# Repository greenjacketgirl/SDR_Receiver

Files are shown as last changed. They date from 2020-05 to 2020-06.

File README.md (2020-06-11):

# SDR Receiver Project

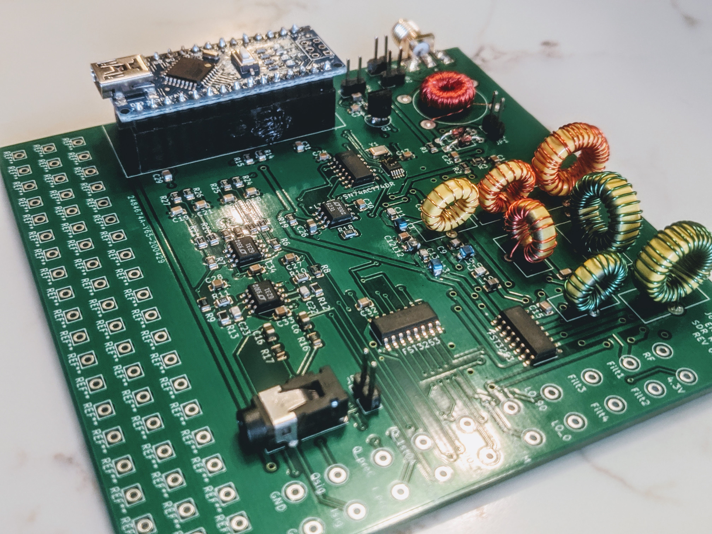
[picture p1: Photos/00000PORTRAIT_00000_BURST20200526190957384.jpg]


**Introduction** | This project was created in the scope of the the class ENGR 357 "Engineering Electronics II" conducted through online learning at Walla Walla University. We ([Jordyn Watkins](https://github.com/greenjacketgirl) and [Joshua Silver](https://github.com/JoshSilver8)) were tasked with designing, building, and testing a *software defined radio (SDR) receiver*. Our radio is designed to listen to frequencies ranging from 500kHz - 50MHz designed to be used in conjunction with [Quisk](https://github.com/greenjacketgirl/SDR_Receiver/wiki/9.-Software), a free open source SDR software. For more information on the theory, reasoning behind our design choices, and a more in depth look at the results and specs of this project, please refer to the [Wiki](https://github.com/greenjacketgirl/SDR_Receiver/wiki) tab.

**Navigation** | This repository consists of several folders. In this "code" tab, you will find 2 primary folders: Attenuator and Receiver. Within the attenuator file, you will find a folder containing the KiCad files, a folder containing the LTspice simulation files, and a third folder containing build and test notes with pictures and other documentation. The Receiver folder contains 4 main folders: KiCad, LTSpice, Quisk, and Documentation.

**Results** | The radio is in working condition - producing low noise I and Q signals 90 degrees out of phase. The signal discernability is very good, being able to detect signals as small as 0.5uV, and the image rejection is also decent having a 30dB difference between signal and image. For more details on the specs for the radio, visit the [Results](https://github.com/greenjacketgirl/SDR_Receiver/wiki/Results) in the [Wiki](https://github.com/greenjacketgirl/SDR_Receiver/wiki).

**Credits** | This project was created with a lot of help from our professor, Dr. Frohne. The files under the Quisk folder are primarily his. See his github profile at https://github.com/frohro/ 

**Status of Project** | Visit the "issues" tab to see errors and fixes for this project - which should provide a more in depth explanation for the quote "status" of the project. You can also visit the "Wiki" page or view the documentation files in the folders for a description of build and test process when troubleshooting issues.

REVISION 1: _05/26/2020  Build Phase and Troubleshooting Hardware_ |
REVISION 2: _06/04/2020 Test Phase and Troubleshooting Quisk Software Integration_ | REVISION 3: _06/10/2020 Working Radio Fine Tuning and Adjustments_

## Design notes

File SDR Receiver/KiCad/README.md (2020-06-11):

# Navigating this folder

This folder contains two versions of the schematic and pcb design. The first design is the collection of files shown. The second revision is located in the folder [Kicad-V2](https://github.com/greenjacketgirl/SDR_Receiver/tree/master/SDR%20Receiver/KiCad/Kicad-V2). This second revision is the schematic updated with the corrections made by hand shown in the [Issues tab](https://github.com/greenjacketgirl/SDR_Receiver/issues). Note that this second revision only has an updated schematic, not an updated pcb. Thus, future work will require further revision of the PCB. 

Primary corrections made in this second revision:
* crystal footprint pin numbers corrected
* pull up resistors on si5351 clock generator connected to VCC instead of GND
* bandpass filter wiring correction on multiplexer
* label correction from tayloe mixer to summing op-amps

I tried to include the .pretty and library files for the footprints and schematic symbols I used. If you have a difficult time seeing the footprints for some reason, you can also refer to our digikey BOM in the [documents section](https://github.com/greenjacketgirl/SDR_Receiver/tree/master/SDR%20Receiver/Documentation) to look up the part on the [digikey website](https://www.digikey.com) and download the respective footprint from there. You may need to also make corrections to the PCB board after uploading a new symbol and footprint .pretty file.

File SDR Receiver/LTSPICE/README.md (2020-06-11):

**LTspice Simulations |** A description of what each simulation file models

* The [BypassFilterSim](https://github.com/greenjacketgirl/SDR_Receiver/blob/master/SDR%20Receiver/LTSPICE/BypassFilterSim.asc) file essentially contains the simulation of the entire board: Input signal biasing, bandpass filters, tayloe mixer, summing amps, and low-pass filter. This simulation inludes a transients analysis as well as an ac analysis which was useful for the analysing the bandpass filters. We started to attempt a simulation of the noise in the circuit - but this analysis isn't complete yet and is something that can be addressed as future work in the project. See the [issues section number 10 thread](https://github.com/greenjacketgirl/SDR_Receiver/issues/10) for more info on this goal. 

* The [TayloeMixerSim](https://github.com/greenjacketgirl/SDR_Receiver/blob/master/SDR%20Receiver/LTSPICE/TayloeMixerSim.asc) is just a simulation nof the tayloe mixer and following op-amps. In there, I was experimenting with different filter and amplification designs. The final design I went with was included in the [BypassFilterSim](https://github.com/greenjacketgirl/SDR_Receiver/blob/master/SDR%20Receiver/LTSPICE/BypassFilterSim.asc) file.

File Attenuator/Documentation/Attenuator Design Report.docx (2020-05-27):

Attenuator Design

Criteria: We need a step attenuator capable of going from 5mV, zero to peak, to 1uV RMS or maybe 0.5uV RMS, to test our radio receivers using the Analog Discovery 2 boards from Digilent. You should download and install the Waveforms program. You can run it before you receive your Analog Discovery 2 board and see that the lowest output from the board is 5mV, zero to peak. It is important that you realize the stray capacitance and mutual inductance can bypass your attenuator if you don’t design it correctly. We need these attenuators to work to at least 30MHz. I suggest using at least five stages, and 0.1” headers and jumpers for the switches needed. Model your design in LTSpice for the highest attenuation at 30 MHz to make sure it will work. If you have trouble, contact me, and I can help. I have only done a very quick approximation to be fairly certain this should be possible. Then design the PCB in KiCad. As you do, try to make the traces have a characteristic impedance, Z0 of fifty ohms. There is a calculator in KiCad that will help you with that problem. You can choose if you want surface mount or through hole components. We are sending you soldering irons, but they probably are not as good as the school’s irons, so soldering surface mount components may be more difficult for you.

Design: I started by determining the amount of attenuation we needed in terms of decibels. This was done using the equation:

dB_v =20log_10 ((V_(OUT))/(V_(IN)))dB

where in our case, V_(OUT) =0.5μV and V_(IN) =5mV . Thus, our decibel attenuation was determined to be:

dB_v =20log_10 ((0.5×10^(-6))/(5×10^(-3)))dB=-80 dB

We can now design our attenuator so that we have a total decibel drop close to 80. However, to compensate for the capacitance in the circuit (capacitance values calculate in appendix A), and to adjust to have a value of around 0.5μV at a frequency of 20MHz while having minimal distortion at 30MHz , we chose a loss of 74 dB. The stray capacitance was factored into the simulation, but mutual inductance was neglected, as we presumed that it would be negligible since we planned on constructing the attenuator in a linear fashion. We decided to have 5 stages, each with a loss of 14.8 dB for simplicity and to minimize the amount of distortion the circuit sees at higher frequencies. To calculate the resistor values, we performed the following calculations, whose results are summarized in table 1.

K=10^(15/20) =5.49541

R1,R3=Z((K+1)/(K-1))=50((5.49541+1)/(5.49541-1))=71.629Ω

R2=Z((K^2 +1)/(2K))=Z((5.49541^2 +1)/(2(5.49541)))=136.14 Ω

We then looked a common resistor value table and took the closest actual resistor values to place in our simulation in LTSpice.

dB Loss | K Factor | 50 Ω Impedence
| | R1, R3 | R2
14.8 | 5.49541 | 73.2 | 133

Table 1. Calculated resistor values based on a 15 dB attenuation per stage of the attenuator circuit.

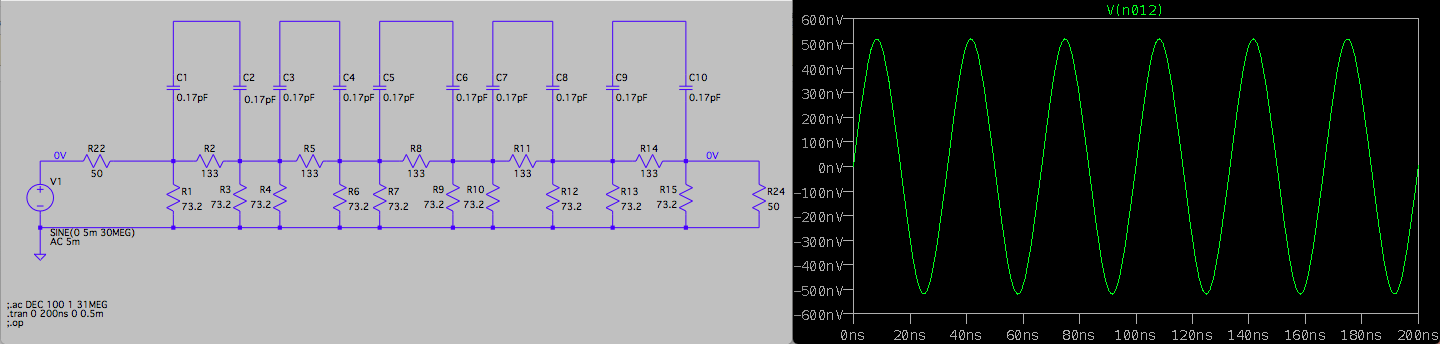
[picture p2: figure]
../../../../Dropbox/Screenshots/Screenshot%202020-04-02%2013.54.24.p
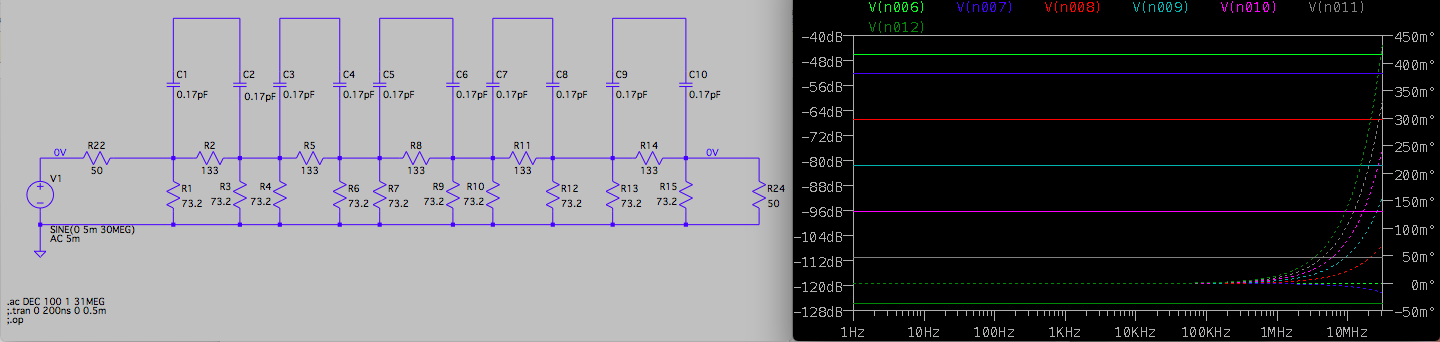
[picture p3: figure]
../../../../Dropbox/Screenshots/Screenshot%202020-04-02%2013.55.32.p

Simulation: The LTSpice simulation was modeled as shown in Figure 1 and Figure 2. From these simulations, we see that even with the stray capacitance factored into the simulation, the circuit functions as expected. An input signal of 5mV is attenuated to somewhere between 0.35uV to 1uV depending on the frequency of the signal.

Figure 2. The attenuator circuit simulation in LTSpice with transient analysis shown on the right at a frequency of 20MHz and input signal of amplitude 5mV. We see that the output voltage is just at 0.5uV therefore meeting the design criteria.

Figure 1.The attenuator circuit simulation in LTSpice with ac analysis shown on the right, with probes at each stage in the attenuator. The magnitude across the load resistor starts at -128dB, increasing to -126.8dB by 32MHz.

PCB Design: We used KiCad to design our PCB. We are using jumpers between pins as our pseudo switches, therefore 1x3 connectors were used to model each switch. We decided on using through hole resistors (THT-resistors) for ease of soldering them onto the completed board. For power supply to the board, we used coaxial connectors. The parts list is provided in the figure below, along with documentation of the KiCad Schematic and PCB Design. We ordered the boards to be printed from JLC PCB.

Resistor_THT:R_Axial_DIN0207_L6.3mm_D2.5mm_P7.62mm_Horizontal

PCB calculator:

TRANSLINE

Microstrip Line

Ordered from JLC PCB

Appendix A: Created by Dr. Frohne

Jordyn Watkins ENGR 357 Attenuator Design 04/03/2020

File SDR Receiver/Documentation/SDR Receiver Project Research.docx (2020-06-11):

SDR Receiver Project Research

Quadrature Mixers, IQ Demodulation, and the Tayloe Detector

Reference: https://www.youtube.com/watch?v=JuuKF1RFvBM

MIXER DESIGN: When we talk about mixers, we are usually implying we are talking about multiplying mixers.

sin(w_1 t)sin(w_2 t)=1/2cos(w_1 w_2 )t-1/2cos(w_1 w_2 )t

+/- IF

RF

LO

Essentially, the local oscillator acts as a theoretical “switch” that turns on and off. In order to tell if we are at the +IF or the –IF, we need a reference frequency. And that’s when we need a phase parameter as our reference. Thus, we need waves 90 degrees out of phase with each other out of the output (the I and Q signals). We essentially need to take our input signal (RF) and break it down into two smaller components (I and Q).

If we have a signal positive with respect to the local oscillator, then we have this equation:

e^(jwt) =cos(wt)+jsin(wt) where cos(wt) is the I signal, and jsin(wt) is the Q signal.

The I wave is leading and the Q wave is lagging.

If we have a signal negative with respect to the local oscillator, then we have this equation:

e^(-jwt) =cos(wt)-jsin(wt) where cos(wt) is the I signal, and jsin(wt) is the Q signal.

The Q wave is leading, and the I wave is lagging.

So, when we talk about I and Q, we mean that the I signal is the “in phase” or our “reference” signal which is static (as indicated by the equation where the cosine term is unchanged in the equations. And the Q signal is the quadrature signal. It is essentially flipped 180 degrees so that it appears like it is either leading or lagging the I signal by 90 degrees. If it is lagging, then it is above our local oscillator frequency, whereas if it is leading, then it is below the local oscillator frequency.

Using a Tayloe Mixer: utilizes 4 to 1 multiplexer IC. Called Dan tayloe mixers after the guy who popularized them. Only need one multiplexer, they are very cheap (about 50 cents apiece), they require very low local oscillator drive levels (don’t need a lot of power out of your local oscillator), have high 3rd order intercept (so immune to being overloaded by strong levels), and have very low insertion loss (about 1dB). How they work: they have select lines s0 and s1, where the I signal of the local oscillator connects to s0 and the Q signal of the local oscillator connects to s1. Since the I and Q signals are 90 degrees out of phase, we essentially see this as an input to the tayloe mixer select lines:

00 01 11 10 00 01 11 10 00 01 11 10

So the input signal into the multiplexer will be the RF signal, and the output will be a combination of 0, 90, 180, and 270 degree signals. Each one *starts sampling at the corresponding degree. Thus, we have each of the four signals out of phase with the next.

Note, we need capacitors on the outputs of the tayloe mixer multiplexer. The purpose of these capacitors is to sample and hold the voltage that they see. They will track whatever voltage they see while the RF signal is connected to them.

For instance – when the RF and LO signals are the same, we will see that the 0 deg will be the peak voltage value, the 90 deg will be at 0V, and the 180 deg at the minimum voltage value, and the 270 deg will again be at 0V. BUT, if the RF and LO are at slightly different frequencies, then instead of seeing the maximum, minimum and 0V, we will instead start to see this phase shift at the frequency difference over time. Thus, we have our down-converted signal, but in four parts instead of just two. These are our quadrature outputs. Where 0 deg is complimentary to 180 deg, and 90 deg is complimentary to 270 deg. So, these complimentary outputs are put into a summing amp so that we aren’t throwing away any signals. Classically, we use the FST3253, which is a dual 4 to 1 multiplexer. Typically, the RF signal is actually applied to both of the inputs on the dual multiplixer – and this is just done to lower the resistance that the chip provides to the signal. The typical resistance is 4 ohms, but if you use two inputs, then it lowers it to 2 ohms. The corresponding outputs are also tied together for the same reason.

The way you select the sample capacitors is to set the low pass cut off frequency that you want. This essentially becomes a low pass filter when examined in conjunction with the 50 ohm impedence of the input signal. But it’s important to note that the input resistance is split between 4 outputs, so each output only sees ¼ of the input resistance, which is 50/4 = 12.5 ohms. But then we also need to add in the resistance from the multiplexer.

jX = 1/(jwC) => 12.5 = 1/(2*pi*f*C). If we choose a cut off frequency, then we can calculate the capacitance for this low pass filter.

BANDPASS FILTER DESIGN:

CRYSTAL AND CLOCK GENERATOR FOR LOCAL OSCILLATOR:

SUMMING AMPS AND LOW PASS FILTER DESIGN:

Jordyn Watkins ENGR 357 04/06/2020

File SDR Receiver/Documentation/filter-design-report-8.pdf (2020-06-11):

## Filter Design Report

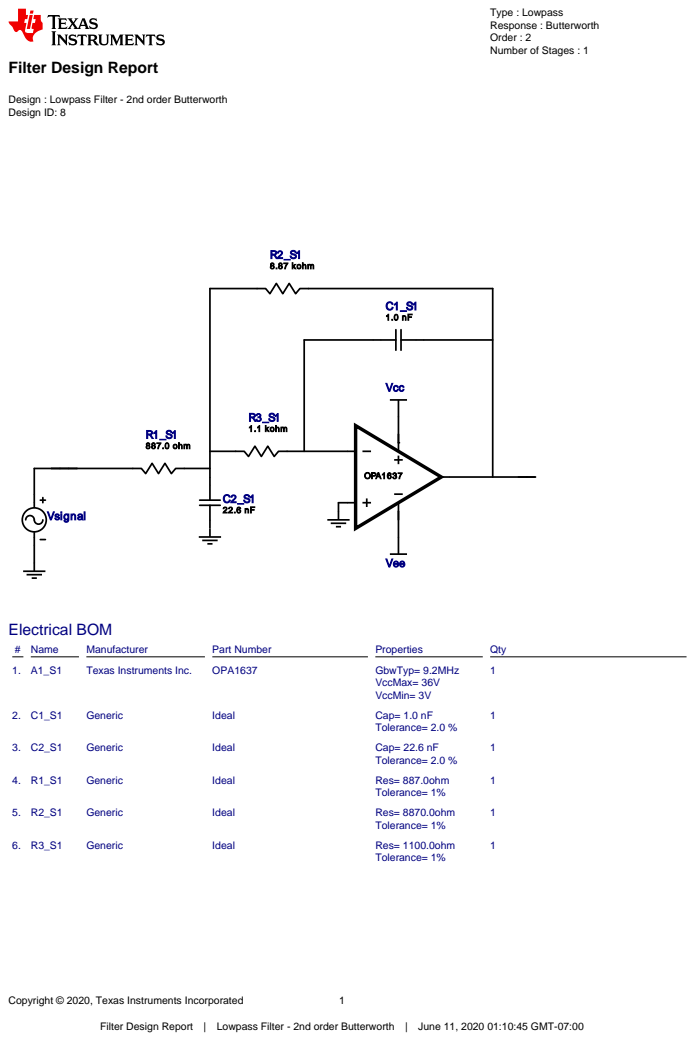
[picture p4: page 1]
Copyright © 2020, Texas Instruments Incorporated; Vsignal; OPA1637; R1_S1 887.0 ohm; R2_S1 8.87 kohm; R3_S1 1.1 kohm; Vcc; Vee; Electrical BOM; # Name; Manufacturer; Part Number; Properties; Qty; Texas Instruments Inc.; GbwTyp= 9.2MHz; VccMax= 36V VccMin= 3V; Generic; Ideal; Cap= 1.0 nF; Tolerance= 2.0 %; Cap= 22.6 nF; Res= 887.0ohm; Tolerance= 1%; Res= 8870.0ohm; Res= 1100.0ohm

Type : Lowpass
Response : Butterworth
Order : 2
Number of Stages : 1

Design : Lowpass Filter - 2nd order Butterworth
Design ID: 8

Filter Design Report | Lowpass Filter - 2nd order Butterworth | June 11, 2020 01:10:45 GMT-07:00

Filter Design

## Sensitivity Analysis

# Name | Series | Tolerance

1. Cap | E48 | 2%
2. Res | E96 | 1%

## Design Inputs

# | Name | Value | Description

1. FilterType | lowpass
2. FilterResponse | Butterworth
3. FilterOrder | 2.0
4. FilterTopology | Multiple Feedback
5. NumberOfStages | 1.0
6. PassbandFrequency | 10.7 k
7. StopbandAttenuation | -40.001
8. StopbandFrequency | 107.0 k
9. Gain | 10.0
10. DualSupply | +/-5.00 V | Power supply(s) to active chips
11. ResistorTolerance | E96 | Resistor series - 1% Passive resistor tolerance
12. CapacitorTolerance | E48 | Capacitor series - 2% Passive capacitor tolerance

## Design Assistance

1. OPA1637 Product Folder : http://www.ti.com/product/OPA1637 : contains the data sheet and other resources.

# Filter Stage :1

Cutoff Frequency | 10.718 kHz
Min GBW Reqd | 7.566 MHz
Stage Gain | 10.0 V/V
Stage Q | 708.132 m
Stage Topology | Multiple Feedback
| R2_S1 8.87 kohm

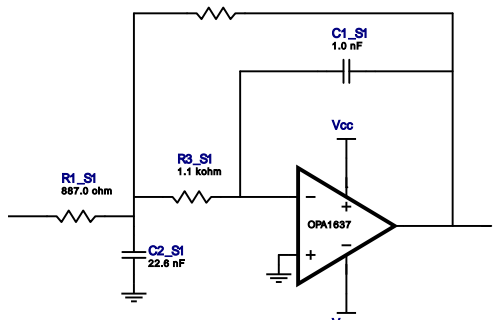
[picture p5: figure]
OPA1637; R1_S1 887.0 ohm; R3_S1 1.1 kohm; Vcc

Vee

## Electrical BOM

# Name | Manufacturer | Part Number | Properties | Qty

1. A1_S1 | Texas Instruments Inc. | OPA1637 | GbwTyp= 9.2MHz VccMax= 36V VccMin= 3V | 1
2. C1_S1 | Generic | Ideal | Cap= 1.0 nF Tolerance= 2.0 %

1

3. C2_S1 | Generic | Ideal | Cap= 22.6 nF Tolerance= 2.0 %

1

4. R1_S1 | Generic | Ideal | Res= 887.0ohm Tolerance= 1%

1

5. R2_S1 | Generic | Ideal | Res= 8870.0ohm Tolerance= 1%

1

6. R3_S1 | Generic | Ideal | Res= 1100.0ohm Tolerance= 1%

1

Important Notice and Disclaimer

TI provides technical and reliability data (including datasheets), design resources (including reference designs), application or other design advice, web tools, safety information, and other resources AS IS and with all faults, and disclaims all warranties. These resources are intended for skilled developers designing with TI products. You are solely responsible for (1) selecting the appropriate TI products for your application, (2) designing, validating and testing your application, and (3) ensuring your application meets applicable standards, and any other safety, security, or other requirements.

These resources are subject to change without notice. TI grants you permission to use these resources only for development of an application that uses the TI products described in the resource. Other reproduction and display of these resources is prohibited. No license is granted to any other TI intellectual property right or to any third party intellectual property right. TI disclaims responsibility for, and you will fully indemnify TI and its representatives against, any claims, damages, costs, losses, and liabilities arising out of your use of these resources.

Providing these resources does not expand or otherwise alter TI's applicable Terms of Sale or other applicable terms available either on ti.com or provided in conjunction with TI products.

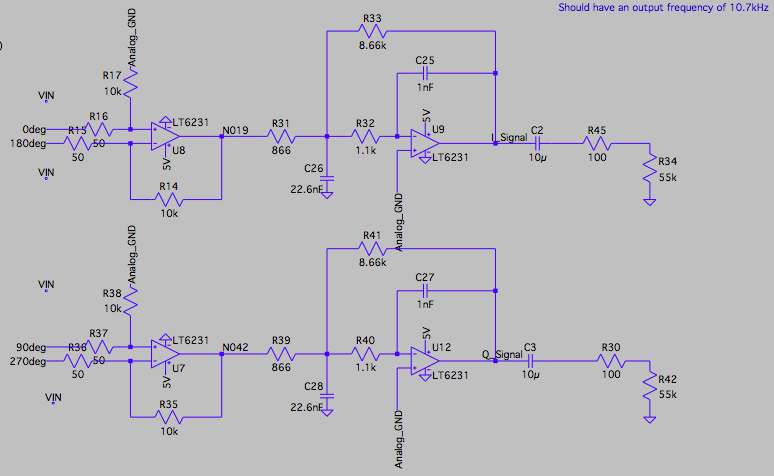
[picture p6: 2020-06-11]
Photos/Screenshot 2020-06-11 01.46.17.png

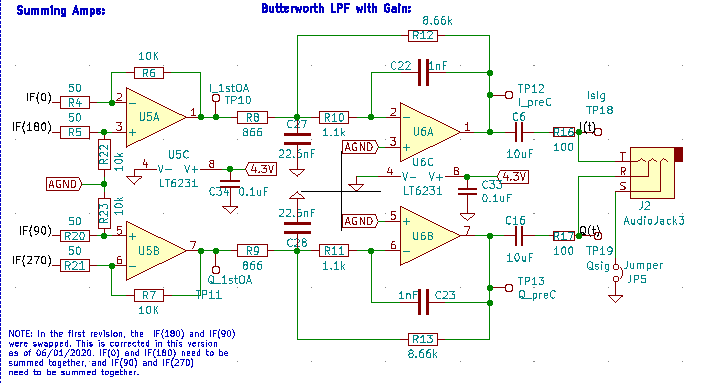
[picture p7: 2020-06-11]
Photos/Screenshot 2020-06-05 09.06.02.png

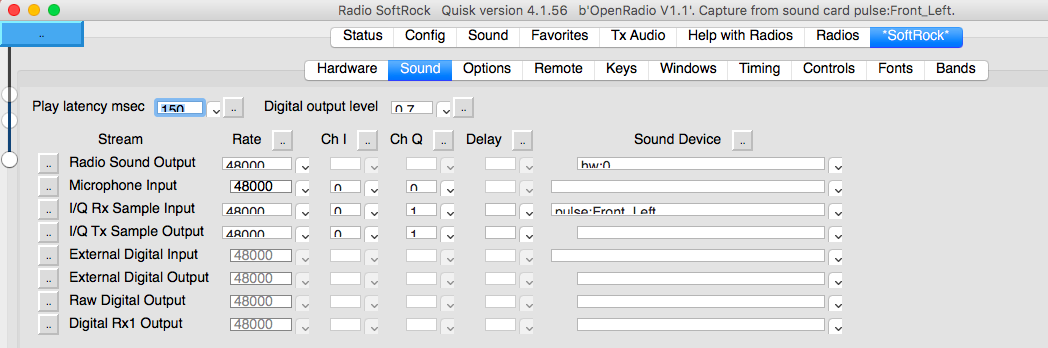
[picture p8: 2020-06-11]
Photos/Screenshot 2020-06-01 17.20.05.png

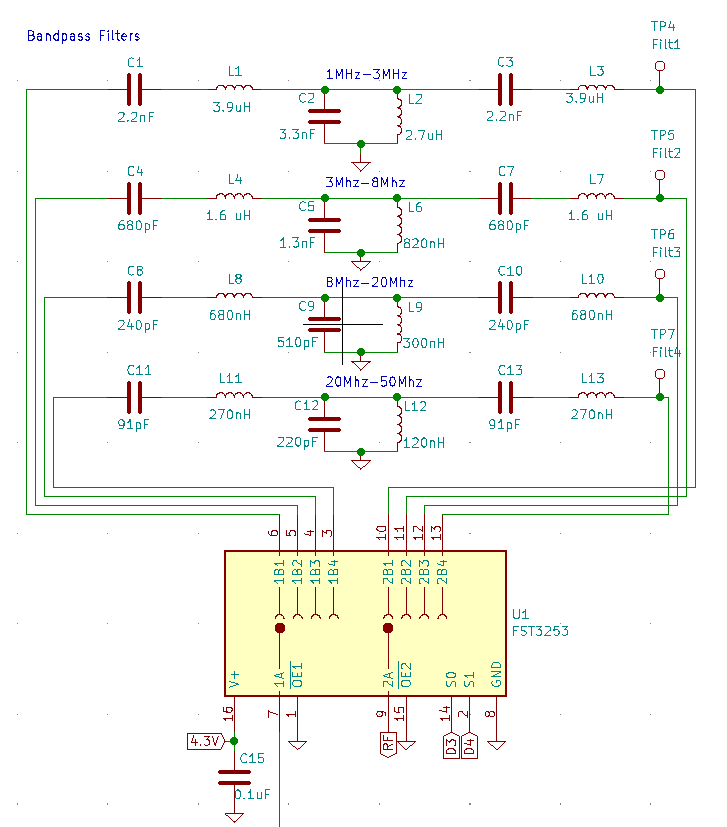
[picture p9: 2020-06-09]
Photos/Bandpass Filter Sch.png

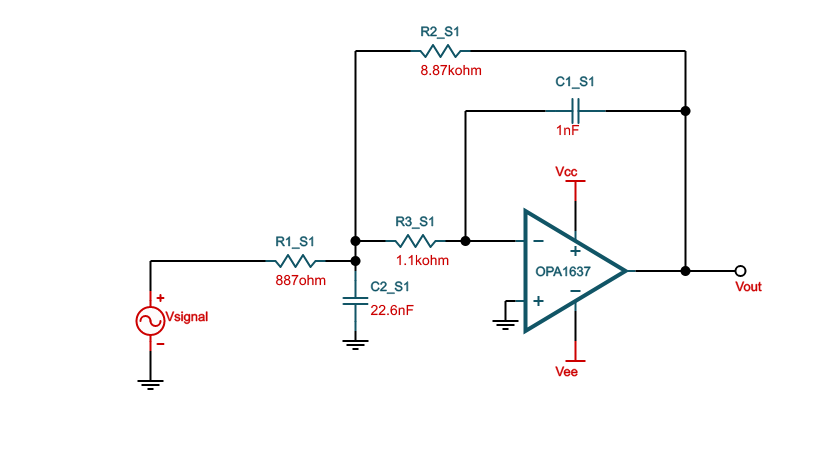
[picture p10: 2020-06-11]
Photos/Screenshot 2020-06-11 01.09.24.png

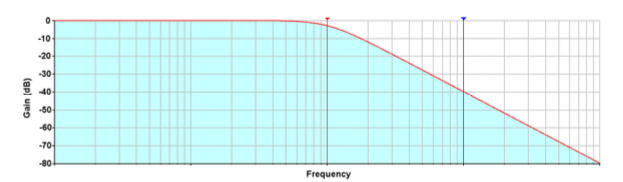
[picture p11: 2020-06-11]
Photos/Screenshot 2020-06-11 00.57.46.png

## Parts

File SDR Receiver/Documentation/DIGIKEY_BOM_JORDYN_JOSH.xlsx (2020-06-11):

Manufacturer Part Number | Manufacturer | Digi-Key Part Number | Customer Reference | Reference Designator | Packaging | Part Status | Quantity | Unit Price | Extended Price | Quantity Available | Mfg Std Lead Time | Description | RoHS Status | Lead Free Status | REACH Status
C0805C104Z5VACTU | KEMET | 399-1177-1-ND |  |  | Cut Tape (CT) | Active | 12 | 0.057 | $0.68 | 743266 | 8 Weeks | CAP CER 0.1UF 50V Y5V 0805 | ROHS3 Compliant | Lead free | REACH Unaffected
C0805C106K8PACTU | KEMET | 399-4925-1-ND |  |  | Cut Tape (CT) | Active | 4 | 0.16 | $0.64 | 311400 | 13 Weeks | CAP CER 10UF 10V X5R 0805 | ROHS3 Compliant | Lead free | REACH Unaffected
C0805C222KARACAUTO | KEMET | 399-16649-1-ND |  |  | Cut Tape (CT) | Active | 2 | 0.29 | $0.58 | 14279 | 11 Weeks | CAP CER 0805 2.2NF 250V X7R 10% | ROHS3 Compliant | Lead free | REACH Unaffected
C0805C332KDRACAUTO | KEMET | 399-16654-1-ND |  |  | Cut Tape (CT) | Active | 1 | 0.46 | $0.46 | 3842 | 11 Weeks | CAP CER 0805 3.3NF 1000V X7R 10% | ROHS3 Compliant | Lead free | REACH Unaffected
CC0805KRX7R9BB681 | Yageo | 311-1126-1-ND |  |  | Cut Tape (CT) | Active | 2 | 0.12 | $0.24 | 73294 | 33 Weeks | CAP CER 680PF 50V X7R 0805 | ROHS3 Compliant | Lead free | REACH Unaffected
GRM2165C2A132JA01D | Murata Electronics | 490-8290-1-ND |  |  | Cut Tape (CT) | Active | 1 | 0.19 | $0.19 | 5041 | 10 Weeks | CAP CER 1300PF 100V C0G/NP0 0805 | ROHS3 Compliant | Lead free | Not Available
C0805C910J5GACTU | KEMET | 399-9279-1-ND |  |  | Cut Tape (CT) | Active | 2 | 0.33 | $0.66 | 5865 | 8 Weeks | CAP CER 91PF 50V C0G/NP0 0805 | ROHS3 Compliant | Lead free | REACH Unaffected
C0805C221M5RACTU | KEMET | 399-8039-1-ND |  |  | Cut Tape (CT) | Active | 1 | 0.1 | $0.10 | 94549 | 8 Weeks | CAP CER 220PF 50V X7R 0805 | ROHS3 Compliant | Lead free | REACH Unaffected
C0805C241J5GAC7800 | KEMET | 399-15478-1-ND |  |  | Cut Tape (CT) | Active | 2 | 0.33 | $0.66 | 5228 | 11 Weeks | CAP CER 240PF 50V NP0 0805 | ROHS3 Compliant | Lead free | REACH Unaffected
C0805C511J5HACAUTO | KEMET | 399-16590-1-ND |  |  | Cut Tape (CT) | Active | 1 | 0.19 | $0.19 | 6248 | 11 Weeks | CAP CER 0805 510PF 50V ULTRA STA | ROHS3 Compliant | Lead free | REACH Unaffected
08051C163JAT2A | AVX Corporation | 478-10426-1-ND |  |  | Cut Tape (CT) | Active | 4 | 0.37 | $1.48 | 22784 | 12 Weeks | CAP CER 0.016UF 100V X7R 0805 | ROHS3 Compliant | Lead free | REACH Unaffected
C0805C102J5HACAUTO | KEMET | 399-16591-1-ND |  |  | Cut Tape (CT) | Active | 2 | 0.19 | $0.38 | 12845 | 11 Weeks | CAP CER 0805 1NF 50V ULTRA STABL | ROHS3 Compliant | Lead free | REACH Unaffected
C0805C223K5RACTU | KEMET | 399-1163-1-ND |  |  | Cut Tape (CT) | Active | 2 | 0.1 | $0.20 | 402335 | 8 Weeks | CAP CER 0.022UF 50V X7R 0805 | ROHS3 Compliant | Lead free | REACH Unaffected
LT6231CS8#PBF | Linear Technology/Analog Devices | LT6231CS8#PBF-ND |  |  | Tube | Active | 3 | 4.85 | $14.55 | 2241 | 10 Weeks | IC OPAMP GP 2 CIRCUIT 8SO | ROHS3 Compliant | Lead free | REACH Unaffected
SN74CBT3253CDR | Texas Instruments | 296-19206-1-ND |  |  | Cut Tape (CT) | Active | 2 | 0.58 | $1.16 | 5971 | 6 Weeks | IC MUX/DEMUX DUAL 4:1 16SOIC | ROHS3 Compliant | Lead free | REACH Unaffected
1N914 | ON Semiconductor | 1N914FS-ND |  |  | Bulk | Active | 2 | 0.1 | $0.20 | 14503 | 18 Weeks | DIODE GEN PURP 100V 200MA DO35 | ROHS3 Compliant | Lead free | REACH Unaffected
SN74ACT74DR | Texas Instruments | 296-1079-1-ND |  |  | Cut Tape (CT) | Active | 1 | 0.5 | $0.50 | 2491 | 6 Weeks | IC FF D-TYPE DUAL 1BIT 14SOIC | ROHS3 Compliant | Lead free | REACH Unaffected
FA-238 25.0000MB-C3 | EPSON | SER3691CT-ND |  |  | Cut Tape (CT) | Active | 1 | 0.36 | $0.36 | 17296 | 16 Weeks | CRYSTAL 25.0000MHZ 18PF SMD | ROHS3 Compliant | Lead free | Not Available
0805CS-271EKTS | Delta Electronics/Components | 2035-1233-1-ND |  |  | Cut Tape (CT) | Active | 2 | 0.25 | $0.50 | 3990 | 16 Weeks | CHIP INDUCTOR 270NH10% 350MA 1.0 | ROHS3 Compliant | Lead free | Not Available
CV201210-R68K | Bourns Inc. | CV201210-R68KCT-ND |  |  | Cut Tape (CT) | Active | 1 | 0.1 | $0.10 | 2375 | 18 Weeks | FIXED IND 680NH 150MA 800MOHM SM | ROHS3 Compliant | Lead free | REACH Unaffected
PE-0805CM121JTT | Pulse Electronics Network | 553-1043-1-ND |  |  | Cut Tape (CT) | Active | 1 | 0.31 | $0.31 | 12696 | 70 Weeks | FIXED IND 120NH 350MA 560 MOHM | RoHS Compliant | Lead free | Not Available
0805CS-301EGTS | Delta Electronics/Components | 2035-1241-1-ND |  |  | Cut Tape (CT) | Active | 1 | 0.25 | $0.25 | 3850 | 16 Weeks | CHIP INDUCTOR 300NH2% 330MA 1.2O | ROHS3 Compliant | Lead free | Not Available
RC0805FR-0710KL | Yageo | 311-10.0KCRCT-ND |  |  | Cut Tape (CT) | Active | 6 | 0.1 | $0.60 | 23482238 | 24 Weeks | RES SMD 10K OHM 1% 1/8W 0805 | ROHS3 Compliant | Lead free | REACH Unaffected
RC0805FR-074K7L | Yageo | 311-4.70KCRCT-ND |  |  | Cut Tape (CT) | Active | 2 | 0.1 | $0.20 | 2940632 | 24 Weeks | RES SMD 4.7K OHM 1% 1/8W 0805 | ROHS3 Compliant | Lead free | REACH Unaffected
RC0805FR-072K2L | Yageo | 311-2.20KCRCT-ND |  |  | Cut Tape (CT) | Active | 1 | 0.1 | $0.10 | 3594454 | 24 Weeks | RES SMD 2.2K OHM 1% 1/8W 0805 | ROHS3 Compliant | Lead free | REACH Unaffected
ERA-6AEB8661V | Panasonic Electronic Components | P8.66KDACT-ND |  |  | Cut Tape (CT) | Active | 2 | 0.34 | $0.68 | 4997 | 12 Weeks | RES 8.66K OHM 0.1% 1/8W 0805 | ROHS3 Compliant | Lead free | REACH Unaffected
ERJ-PB6B1101V | Panasonic Electronic Components | P20598CT-ND |  |  | Cut Tape (CT) | Active | 2 | 0.36 | $0.72 | 7877 | 12 Weeks | RES SMD 1.1K OHM 0.1% 1/4W 0805 | ROHS3 Compliant | Lead free | Not Available
CRCW0805866RFKEA | Vishay Dale | 541-866CCT-ND |  |  | Cut Tape (CT) | Active | 2 | 0.1 | $0.20 | 23542 | 11 Weeks | RES SMD 866 OHM 1% 1/8W 0805 | ROHS3 Compliant | Lead free | Not Available
ERJ-6ENF49R9V | Panasonic Electronic Components | P49.9CCT-ND |  |  | Cut Tape (CT) | Active | 4 | 0.1 | $0.40 | 350805 | 16 Weeks | RES SMD 49.9 OHM 1% 1/8W 0805 | ROHS3 Compliant | Lead free | REACH Unaffected
CRG0805F47R | TE Connectivity Passive Product | A126371CT-ND |  |  | Cut Tape (CT) | Active | 4 | 0.1 | $0.40 | 34663 | 16 Weeks | RES SMD 47 OHM 1% 1/8W 0805 | RoHS Compliant | Lead free | Not Available
RC0805JR-071KL | Yageo | 311-1.0KARCT-ND |  |  | Cut Tape (CT) | Active | 1 | 0.1 | $0.10 | 4848264 | 24 Weeks | RES SMD 1K OHM 5% 1/8W 0805 | ROHS3 Compliant | Lead free | REACH Unaffected
BC547BTA | ON Semiconductor | BC547BTACT-ND |  |  | Cut Tape (CT) | Active | 1 | 0.2 | $0.20 | 6111 | 12 Weeks | TRANS NPN 45V 0.1A TO-92 | ROHS3 Compliant | Lead free | REACH Unaffected
SI5351A-B-GT | Silicon Labs | 336-2399-5-ND |  |  | Tube | Active | 1 | 0.92 | $0.92 | 736 | 6 Weeks | IC CLK GENERATOR 200MHZ 10MSOP | Not Available | Lead free | Not Available

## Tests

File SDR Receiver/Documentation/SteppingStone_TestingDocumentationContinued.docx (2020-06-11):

Testing Continued

Since the attenuator is completely working, no further tests were needed for that board. Returning back to the testing of the SDR Receiver, I picked off of where I was last week. Last week, I still needed to rewire the bandpass filters (as this was thought to be the cause of frying the arduino nano). I was able to successfully cut the traces and find some wire I could use to re-solder the pins to the right places. After I finished doing this, I used a multimeter to test the connections to make sure that they were solid. Once I had done everything I could to make sure the bandpass filters were wired correctly, and I had explored any other possibility of the Arduino frying, I mustered up some courage and tried plugging in my Arduino nano once again. This time, it did not burn anything! So, the incorrect wiring in the bandpass filters was, in fact, the problem.

However, an issue remained. I had programmed the Arduino to select the 2nd bandpass filter, but it was still selecting the first filter. After checking the datasheet for the multiplexer, checking my code, and checking the board with no luck – I decided that I could afford to tackle this problem at another time. I figured this was something I could work on after I knew I had the rest of the board working since I knew I had at least the first bandpass filter working.

Proceeding to test the rest of the board, I put in a 760kHz as the input signal, and set the si5351 chip output to 3MHz, so that the local oscillator is at 750KHz. To my disappointment, the tayloe mixer did not output the four signals as I expected it to. Instead of having signals that were at 0 degrees, 90 degrees, 180 degrees, and 270 degrees, the signals were somewhat arbitrary. This was somewhat expected because I saw some of this result in my LTspice simulation. I determined that this was due the “loading” of the circuit – not seeing exactly a 50 ohm impedance at the output. I figured that this was partially the same reason for what I was seeing out of the Tayloe mixer. But, looking at the final output I and Q signals, I discovered that they were exactly 180 degrees out of phase instead of 90 degrees out of phase. After talking to Dr. Frohne and Josh, I found that we had mislabeled the 180 and 90 signals on the inputs to the summing and low pass filter op-amps. Having the signals switched would explain the different loading effects. It also would explain why the final signals were 180 instead of 90 degrees out of phase. I cut the traces on our circuit board and attached new wires to the outputs of the tayloe mixer. Before attaching the wires to the correct op-amps, I decided to check the signals coming out of the mixer without any loading from the op-amps. What I saw on the oscilloscope was an absolute blessing – I saw sine waves that were 0, 90, 180, and 270 degrees out of phase — perfection. Soldering on the wires to the correct op-amp inputs, I again looked at the output from the tayloe mixer and saw the same loading effects that I noticed in the LTspice simulation. Finally, looking at the final I and Q output signals, I saw sine waves that were exactly 90 degrees out of phase and with low noise! This was a cause for celebration!

The next step in testing the radio was getting quisk to work to control the frequency of the local oscillator and selecting the bandpass filter on the mux instead of the Arduino test program. I downloaded the Arduino files from Dr. Frohne’s github, flashed the Arduino with the openradio_quisk.ino file and related .h and .cpp files, changed the file in quisk to the quisk_conf.py file and made edits within the .py files so that the USB port name on my mac matched those in the code. I also needed to change the sound input on the quisk program to the USB :C Media Pulse_Left channel. At this point, I was able to see the signal at two peaks at 760MHz and 740MHz – both of which were 10MHz away from the 750 MHz local oscillator signal set by quisk. Unfortunately, it appeared that my mac was only using 1 channel, instead of 2. As a result, the 769MHz and the 740MHz signal were equal in strength. I essentially had no image rejection. But, this simply a software issue, not an issue with the radio hardware and circuit design. Dr. Frohne helped me contact a forum that is continuing to look into the issue. Hopefully by next week sometime Mr. Eric Thornton will be able to tell me what the best way to manually set the number of channels being used are. Once I am able to use both channels on the sound card, I should be able to test for image rejection.

Some things that still need to be done are

1) Get my sound card to use both channels so that I can test for image rejection
2) Verify / or alter and update the code controlling the use of bandpass filters in the Arduino and python code to work with my multiplexer functions
3) Perform tests for signal discernibility. (this one will definitely be done by the time of the presentation next week and should be included in the documentation)

For more information on testing procedures, I have started adding them to my github repository: https://github.com/greenjacketgirl/SDR_Receiver

Images corresponding to this weeks’ tests:

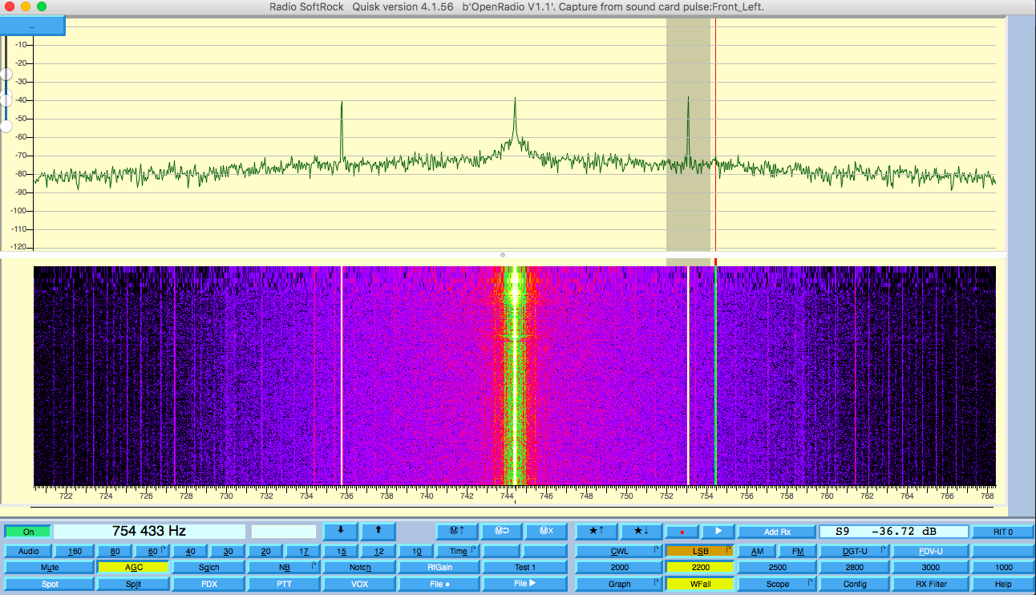
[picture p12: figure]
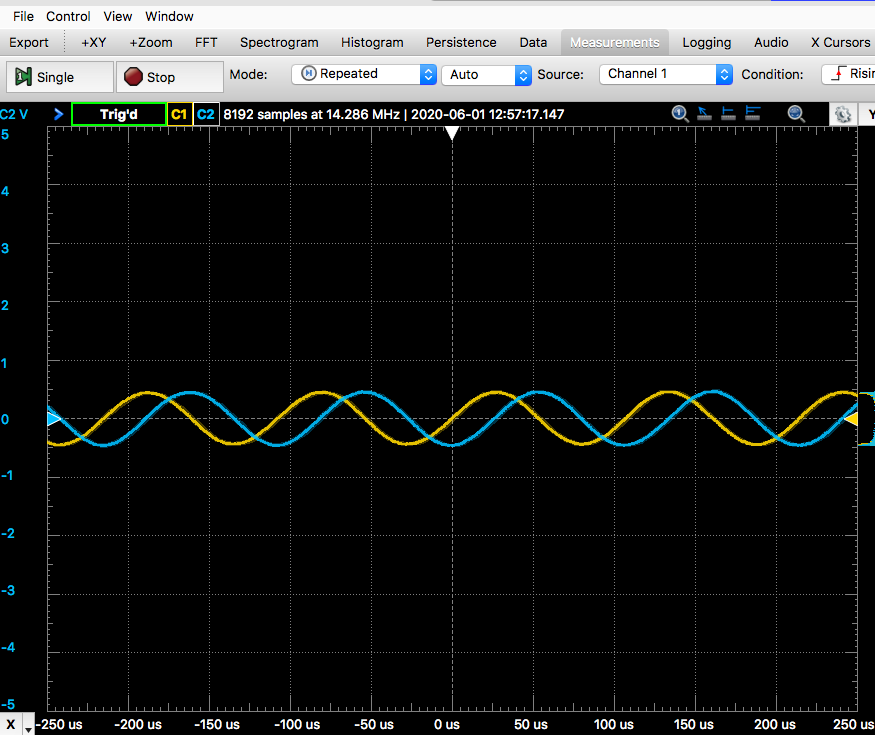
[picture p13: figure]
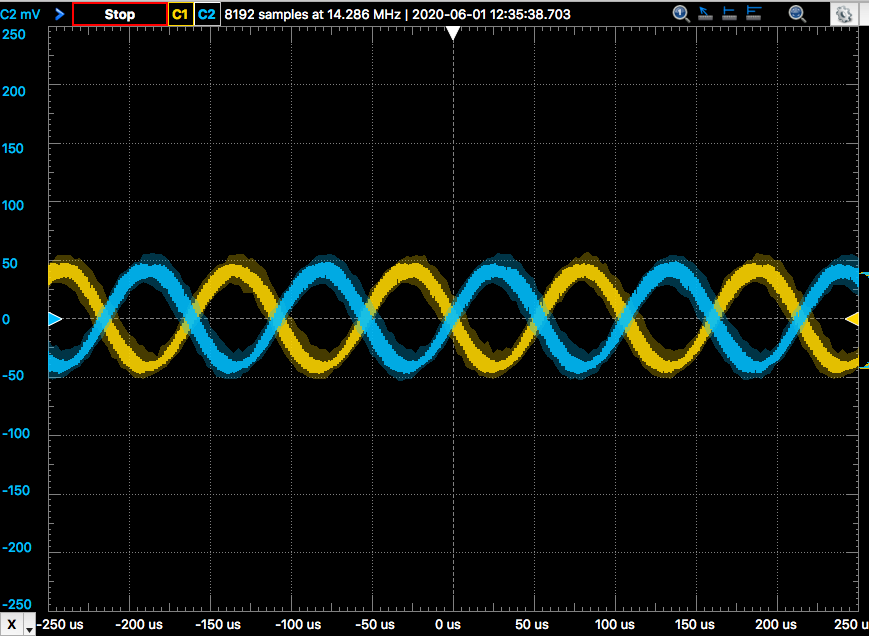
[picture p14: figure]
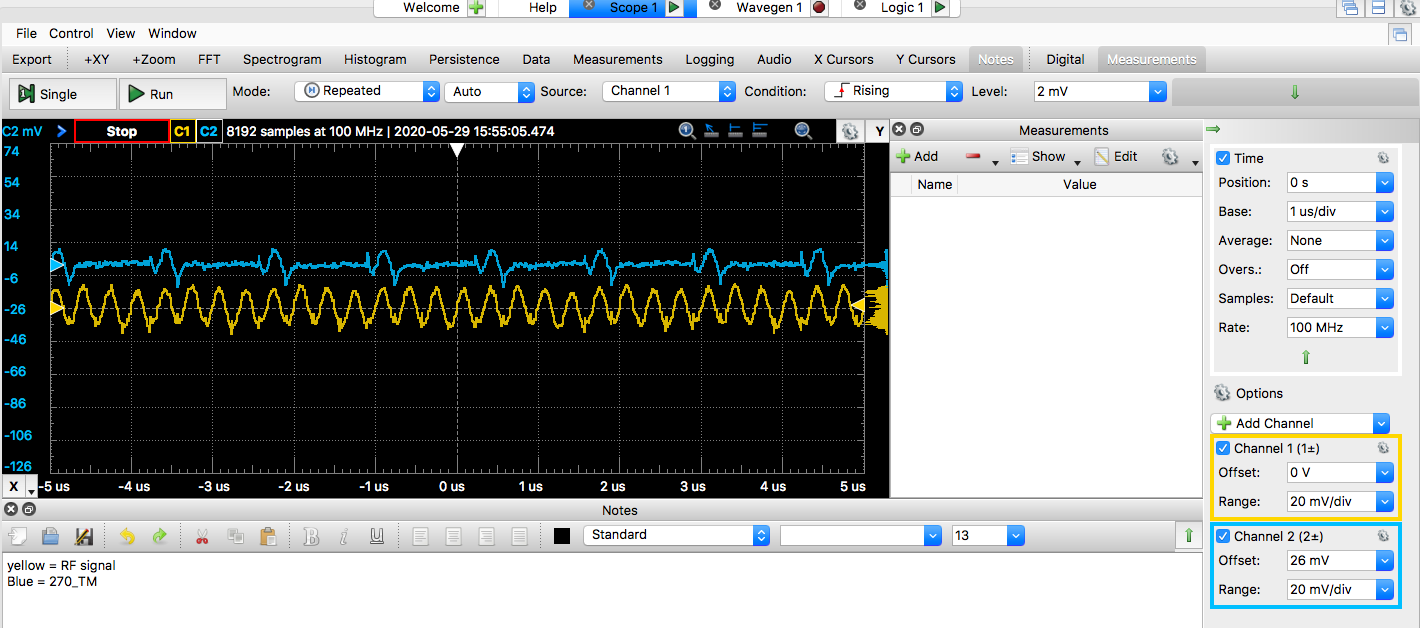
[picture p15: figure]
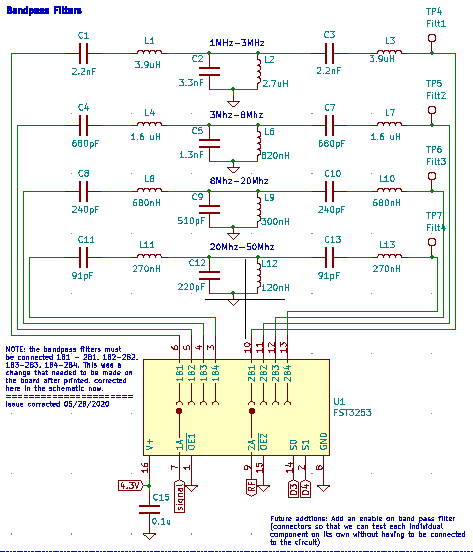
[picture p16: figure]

Jordyn Watkins ENGR357 06/04/2020

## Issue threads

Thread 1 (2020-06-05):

Compiling Arduino Test Code for SI5351

greenjacketgirl, 2020-06-05:
### Background
After building the board, the first system I tried to test was the local oscillator. The first step in testing this system was to program the arduino nano to communicate to the si5351 chip through the sda (A4) and scl (A5) pins. This deals with I2C logic. I downloaded Dr. Frohne's code from his github account linked here: [https://github.com/frohro/IQ_SDR/tree/master/Quisk/Arduino]
Note that for this test program, the only sketch that is needed is in the folder "SDR_Test1". Arduino needs the .ino file to be in a "sketch folder" in order to run - but the arduino software can generate this folder on its own if need be. I also dropped the si5351.h and si5351.cpp files into that same folder.

### Description of Issue
I attempted to flash the arduino nano with Dr. Frohne's arduino test code for the si5351 with the files as described above. It did not work. Let the trouble shooting begin!

greenjacketgirl, 2020-06-05:
### Solution
We discovered that the si5351 library needed to be downloaded/installed directly from arduino. Note that there are two different si5351 libraries. We need the Etherkit version. See photo attached. We can search the library by opening Arduino -> tools -> Manage Libraries -> search "si5351" then click install for the Etherkit si5351 library.

We also need to **remove** the si5351.h and si5351.cpp files we had added to the "SDR_Test1" folder previously. Check to make sure port is correct and correct board (which is "arduino nano") is selected. I also noted that I needed the ATmega328P (Old Bootloader) selected as the processor and the the programmer selected as "ArduinoISP.org"

With this fix, the Arduino was no able to be flashed with the test program.

Closed 2020-06-05.

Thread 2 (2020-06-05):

Crystal Not Outputing a Frequency

greenjacketgirl, 2020-06-05:
### Background
At this point, I now have the arduino nano flashed with the test program. The test program is programmed with a frequency output of 3MHz. This is the frequency I would expect to be coming out of the Clk0 pin of the si5351 with an amplitude of about 20-80mV pk-pk.

### Description of Issue
Connecting it to the receiver board and using an oscilloscope to try and see the output from the si5351 -- there is nothing. Working backwards to try and figure out why the clock generator isn't working, I checked whether the crystal was outputting with a 25MHz frequency. It was not. In fact, it was not outputting anything. Very concerning.

greenjacketgirl, 2020-06-05:
### Solution
The reason why the crystal was not working was that the pin-outs on the schematic were incorrect. Originally, pins 3 and 2 were used as the output pins of the crystal. However, according the the datasheet, the output pins of the crystal must be catty-corner (pins 1 and 3). In order to make this fix, I cut the existing traces on the board, and used extra wire I had to connect the proper pads and pins. The correction is shown in the attached images. This correction resulted in the crystal outputing a 25MHz frequency as anticipated.

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

Closed 2020-06-05.

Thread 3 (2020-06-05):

Quisk Using Only 1 Channel

greenjacketgirl, 2020-06-05:
### Background
Board testing with the arduino test program is finished. The quisk_conf.py is updated with appropriate names for the USB ports for my mac computer and the arduino is flashed with the openradio_quisk.ino and related .h and .cpp files. Quisk opens and displays the signal when the sound input is selected as _USB :C Media_. Quisk is also able to change the local oscillator frequency.

### Description of Issue
While two peaks are displaying on quisk at the correct frequencies as set by the input signal from the digilent analog discovery waveforms program and quisk controlling the local oscillator, the signals are at equal heights even though the output from the board has I and Q signals 90 degrees out of phase. We suspect that the quisk software is only using 1 channel instead of 2. Thus, the peaks are the same height instead of one being significantly greater than the other. So currently, I have no image rejection because of software issues with Quisk.

greenjacketgirl, 2020-06-05:
### update
Thought to be a mac specific issue with the software. Dialoging with help forum through Dr. Frohne to the email group

n2adr-sdr@groups.io
--
Eric Thornton from this group mentioned that there was a way to manually set the number of channels on the sound card. This is still to be investigated.

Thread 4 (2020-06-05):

si5351 - no output signal

greenjacketgirl, 2020-06-05:
### Background
At this point, I know that the arduino is flashed with the correct program and that the crystal outputs going into the si5351 chip is what I expect.

### Description of Issue
The problem is that I still don't have an output from the clock generator. I've looked into the sda and scl pins from the arduino, but they seem to be working just fine.

greenjacketgirl, 2020-06-05:
### Solution
We had the pull-up resistors connected to GND instead of to 3.3V. Cutting the traces on the board and rewiring them according to the updated schematic (attached) fixed the problem. So we now have the si5351 outputing a 3MHz signal as anticipated. This signal passes through the johnson counter (a grey code counter - divide by 4), so that the output of the johnson counter is 750MHz with signals 90 degress out of phase (0_deg LO and 90_deg LO).
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

Closed 2020-06-05.

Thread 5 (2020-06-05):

Arduino 5V USB bypass fried when using it to select bandpass filter

greenjacketgirl, 2020-06-05:
### Background
With the local oscillator working entirely, the next step is checking to see if the signal goes through the bandpass filters properly. To do this, I needed to program the arduino to select the appropiate bandpass filter since I have 4 availiable - each for a different frequency. For the selection process, Josh Silver and I used a multiplexer FST3253 that can choose bandpass filters based on the select lines s0 and s1. Where D4 on the arduino connects to s1 and D3 connects to s0. So I started with programming it to select the second bandpass filter to start with, which should correspond to the following:

s0 (D3) = HIGH
s1 (D4) = LOW

### Description of Issue
Plugged the arduino into the rest of the radio after re-flashing it with code to select the desired bandpass filter. By connecting the arduino, I wasn't expecting anything to happen to the arduino, so I didn't bother checking it to see if it got hot anywhere. However, after trying to see any sort of signal at the local oscillator where there previously was one -- yielded nothing. By the time I checked the arduino, it was behaving unusual. First, the 5V and 3.3V pins were no longer outputing those voltages. Instead they were both outputing about 2.3V. Second, the light indicators on the Arduino were now all off except for the "pow" LED which was very very dim.
Researching this issue, I found the following forum: https://forum.arduino.cc/index.php?topic=152716.0
 "_... have fried the 5v passthrough in the USB chip on the nano_"
"_If the board will not work on USB only power and you have tried more then one USB connector on your PC then you most likely have a bad (open) diode (D1) on your module and replacing it should correct the situation._"

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

pdf of arduino board schematic: https://www.arduino.cc/en/uploads/Main/ArduinoNano30Schematic.pdf

I have not tried to fix the board yet, as I have several others availiable. But discovering what burnt out on the arduino could assist in figuring out _why_ it burnt out. So the major question right now is, _"Why did the arduino burn out? Was it something due to the bandpass filter design?_"

greenjacketgirl, 2020-06-05:
### Solution
Examining the schematic, the only thing that could have afffected the arduino was the multiplexer connected to the bandpass filters. Also, when looking at the schematic, we had the wiring incorrect. Instead of having the following connections for bandpass filters:
_1B1 - 2B1
1B2 - 2B2
1B3 - 2B3
1B4 - 2B4_

We had the following:
_1B1 - 2B4
1B2 - 2B3
1B3 - 2B2
1B4 - 2B1_

I corrected this wiring on the actual board by cutting the traces, then using extra wire to solder the correct connections. After testing to make sure that the connections were good and there weren't any shorts from power to GND, I reflashed the arduino, then connected it to the board. This time, the arduino did not fry! The reason for why this incorrect wiring caused the arduino to burn out is still unknown.

correct schematic of bandpass filter wiring attached here:
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

Closed 2020-06-05.

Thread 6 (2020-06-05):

Incorrect Bandpass Filter Selection

greenjacketgirl, 2020-06-05:
### Background
An arduino nano is flashed with a test program that can be edited to tell the D3 and D4 pins of the arduino to set the select lines of the FST3253 multiplexer to choose the specified bandpass filter.
Where D3 -> s0 and D4 -> s1

### Description of Issue
I programmed the arduino to set the bandpass filter to the second one (3-5MHz) which corresponds to the select lines s0 = HIGH and s1 = LOW. Therefore, in the arduino test code, I set D4 = LOW and D3 = HIGH. But when I used the oscilloscope to look at the bandpass filters, I had a signal passing through the first filter instead of the second. The first filter corresponding to s0 = D3 = LOW and s1 = D4 = LOW.

I have be unable to figure out why this is. I double checked the code (see attached image) and I double checked the truth table in the datasheet for the multiplexer (also attached as an image). After some time working on it, I decided to move on and figure it out later, as I am still able to test the rest of the circuit, just using the 1st bandpass filter and not the second.

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

greenjacketgirl, 2020-06-05:
### update
Since I got the rest of the board working using just the first bandpass filter. I decided to move onto using quisk (_quisk_conf.py_ and _openradio_quisk.ino_) for programming the arduino for setting the local oscillator frequency and the selecting the bandpass filter. Therefore I am disregarding this issue and replacing it with working on getting the bandpass filter selection working with the new arduino and python program

Closed 2020-06-05.

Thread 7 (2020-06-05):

Tayloe Mixer not outputing properly

greenjacketgirl, 2020-06-05:
### Background
The tayloe mixer takes the outputs from the johnson counter to the select lines on the multiplexer FST3253. The 90 degree out of phase signals from the johnson counter work as a grey code counter - so the outputs from the mixer should be in the order -> 0, 90, 270, 80 degrees out of phase.

### Description of Issue
The issue I was having was that instead of getting the expected signal out of the tayloe mixer, I was getting a strange mix of phase differences, with no real pattern to it. I figured that this was most likely due to the loading down of the outputs from the mixer by the following summing op-amps and low pass filters. So I proceeded to test the output I and Q signals. I found that they were exactly 180 degrees out of phase instead of 90 degrees. Problematic.

Pictures of strange things from the output of tayloe mixer shown below:
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

This last image is of the local oscillator output from the johnson counter.
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

greenjacketgirl, 2020-06-05:
### Solution
Examining the schematic once again, Josh and I found that we had the wrong signals being summed in the op-amps. We had the 0 and 90 deg signals being summed together and the 180 and 270 being summed together. this is incorrect. This also explains why the tayloe mixer outputs were not as we expected due to the difference in loading in the signals. Making the correction by cutting the traces and rewiring and soldering to the correct places following the corrected schematic as shown in the attached picture results in a great output. It mirrors the LTspice simulation exactly now. It's important to note that the simulation does not have the expected output at the tayloe mixer due to the loading caused by the op-amps, but the final I and Q signals are still fine even with the seemingly distorted output from the tayloe mixer. Before hooking up the tayloe mixer outputs to the remaining part of the circuit, I used a scope to see if they were what I expected when they weren't being loaded down. The following pictures are the results (yellow is the 0_deg signal, blue changes from 90, 180, 270):
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

Finally reattahing the tayloe mixer output signals to the correct summing amps resulted in the perfect, low noise , 90 degrees out of phase signals - see attached picture
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

Problem solved :)

Closed 2020-06-05.

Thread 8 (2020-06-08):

Need to edit quisk_conf.py and/or openradio_quisk.ino file for correct selection of bandpass filters

greenjacketgirl, 2020-06-08:
### Background
I had previously been unable to have correct selection of the bandpass filters using the arduino test code when first troubleshooting the sdr receiver. I decided to disregard that issue for the time being since I was able to get one of the bandpass filters operating well enough to proceed with troubleshooting the rest of the board. However, this is still an issue that needs to be addressed at some point.

### Description of Issue
I have migrated to using quisk to control the local oscillator frequency instead of the arduino test program. Thus, the scope of the original issue has changed. Now, I will need to figure out how to select the appropriate bandpass filters within the quisk_conf.py and/or openradio_quisk.ino files. Even without this feature working, the user is still able to listen to frequencies ranging from 500kHz to 3.5-4MHz without any issues - Consequently, I am not considering this issue essential to fix at the moment, but should be addressed at some point in the future.

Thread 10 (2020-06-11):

Noise Analysis

greenjacketgirl, 2020-06-11:
### Background
Noise can be a major hindrance to the quality of the signals heard by a receiver. Thus, a noise analysis via simulation on LTSpice can be a good place to start pin pointing possible sources of a significant amount of noise.

### Description of Issue
I would like to propose for future work for the LTspice simulation [BypassFilterSim](https://github.com/greenjacketgirl/SDR_Receiver/blob/master/SDR%20Receiver/LTSPICE/BypassFilterSim.asc) file regarding noise analysis.

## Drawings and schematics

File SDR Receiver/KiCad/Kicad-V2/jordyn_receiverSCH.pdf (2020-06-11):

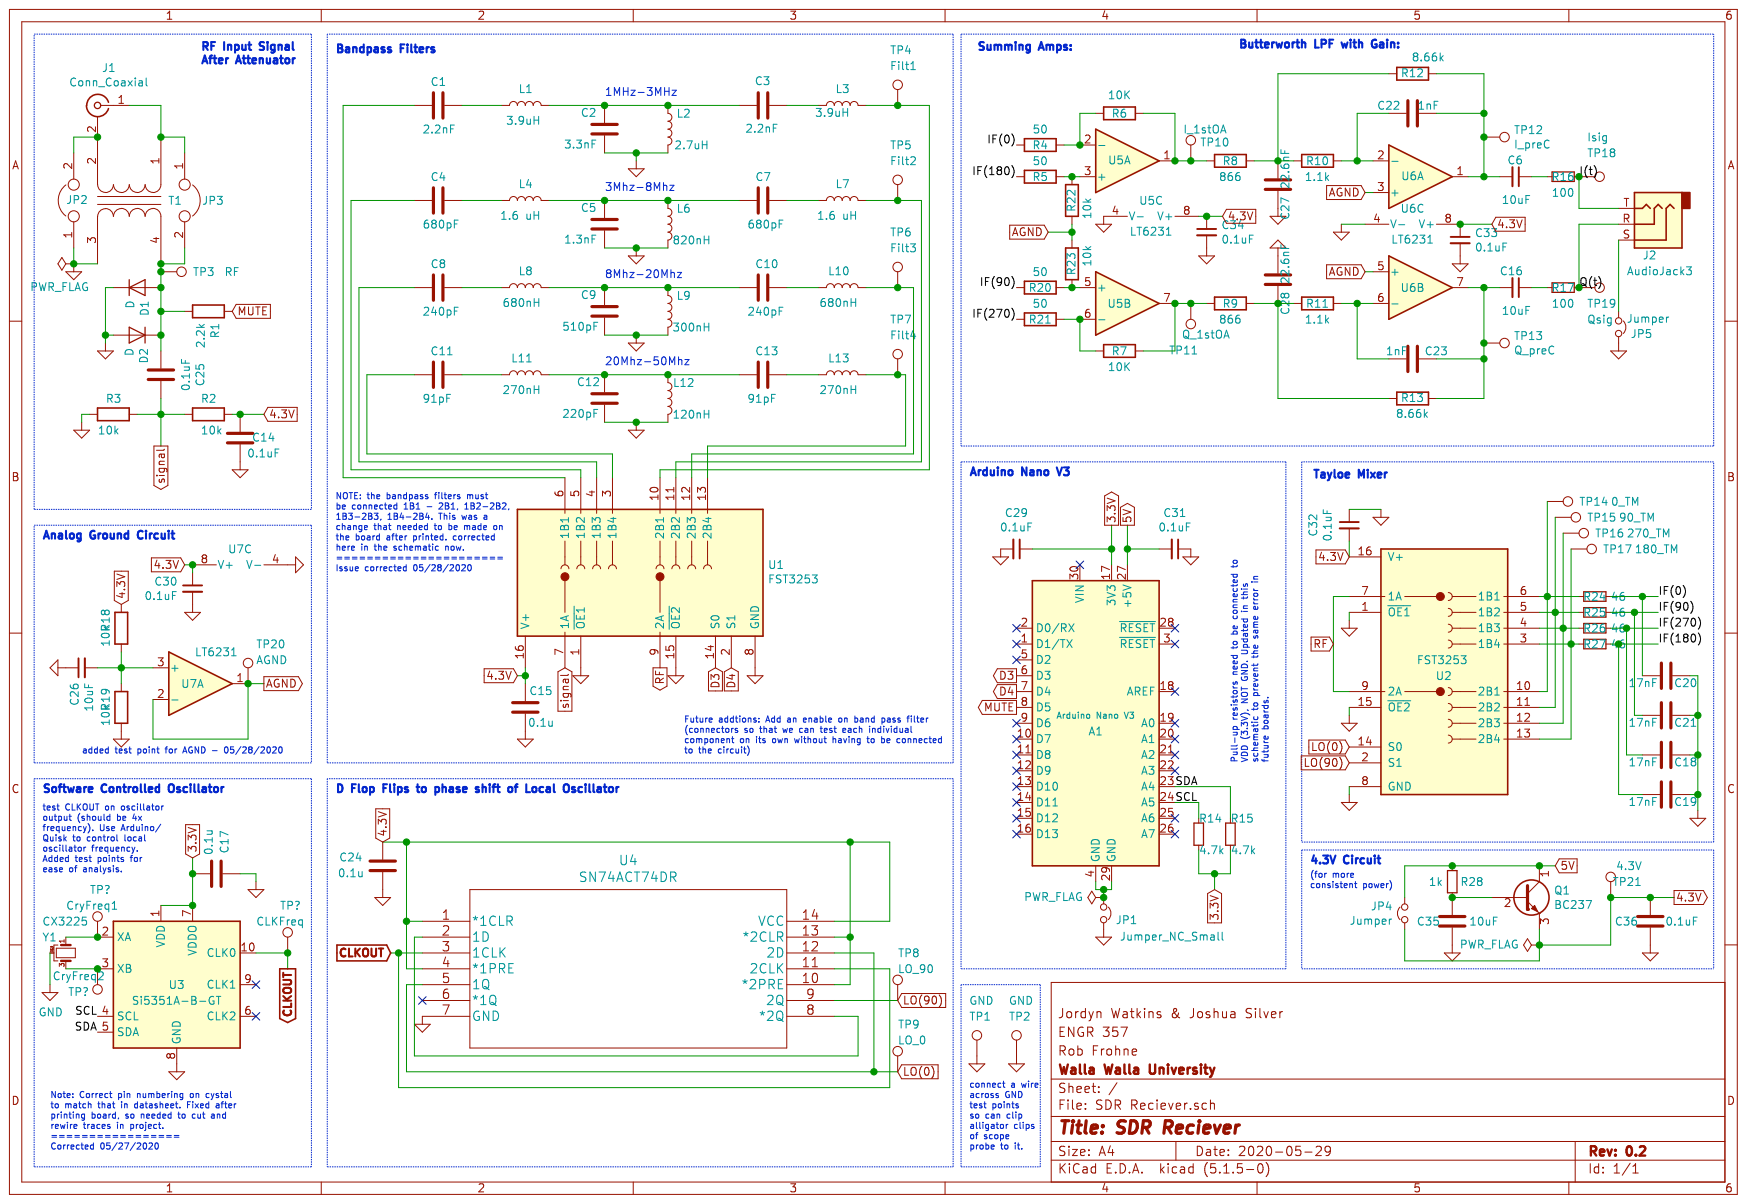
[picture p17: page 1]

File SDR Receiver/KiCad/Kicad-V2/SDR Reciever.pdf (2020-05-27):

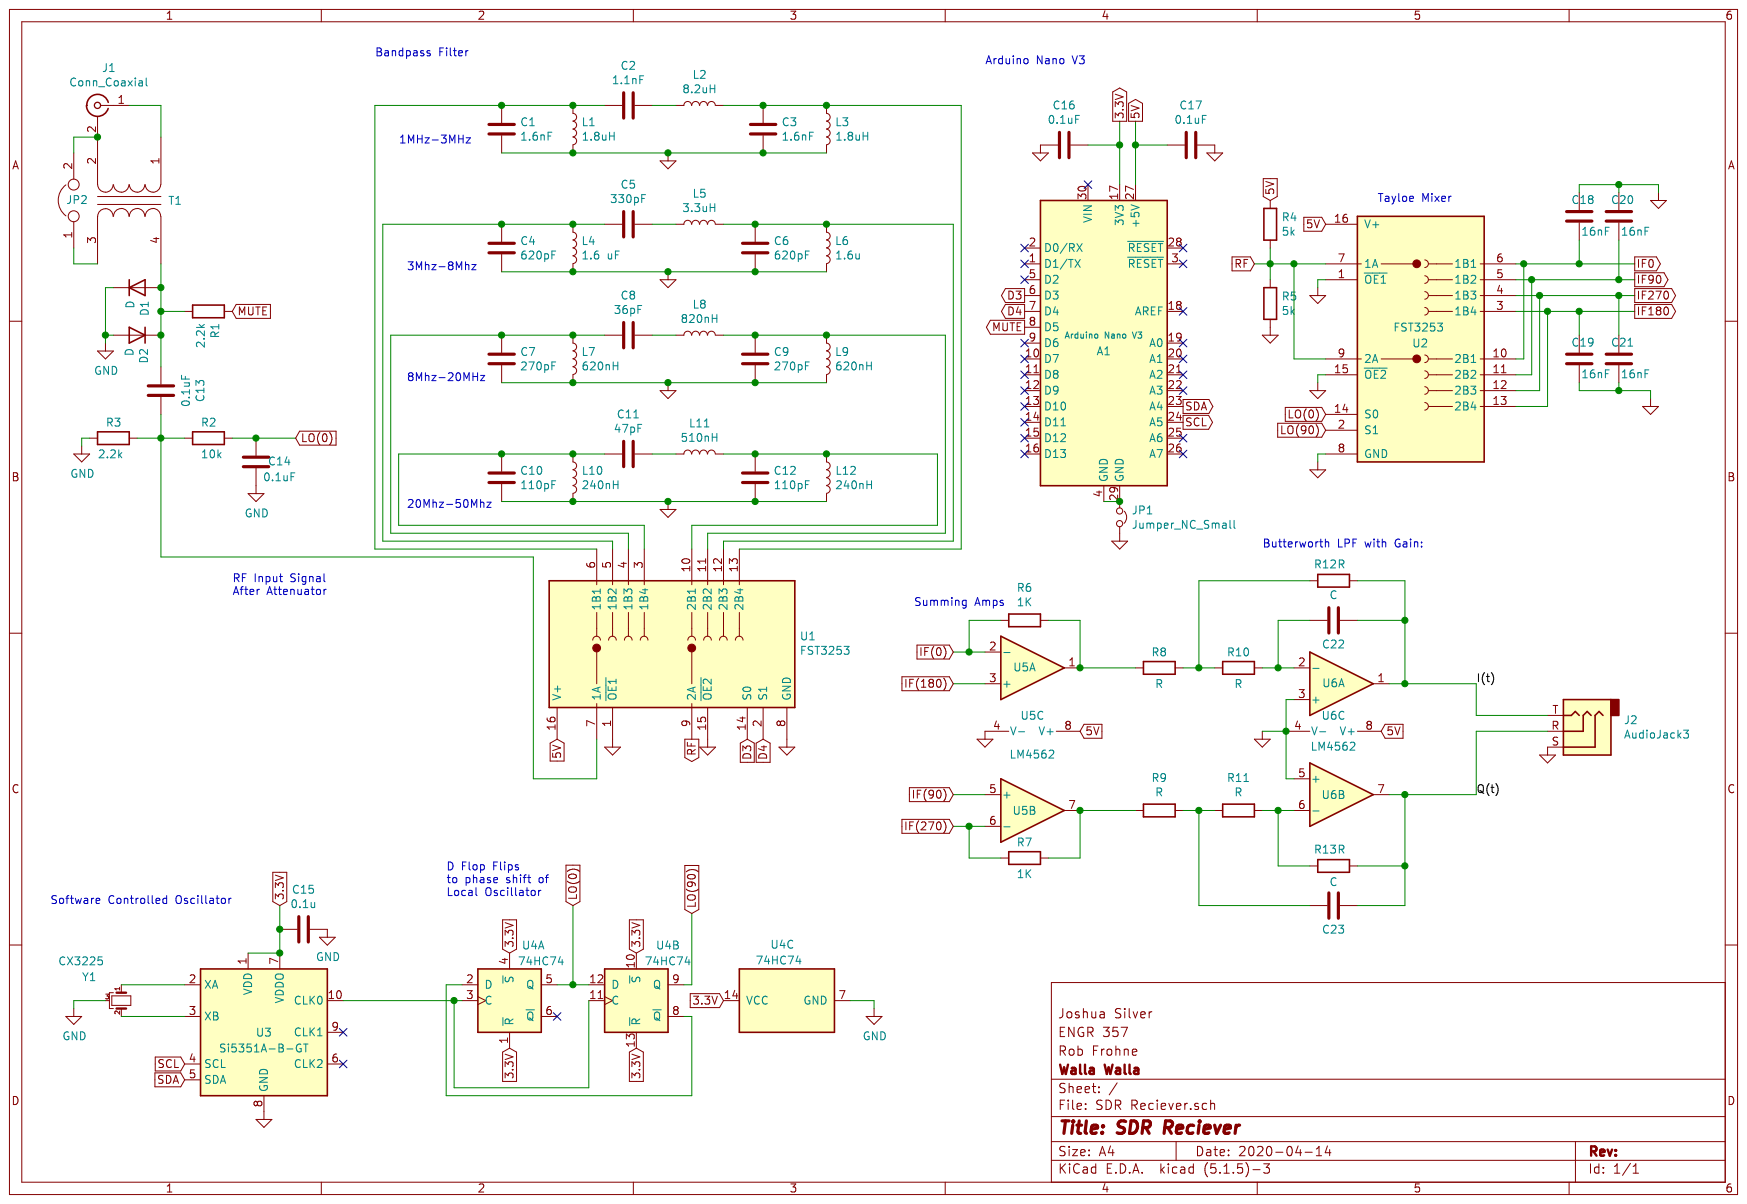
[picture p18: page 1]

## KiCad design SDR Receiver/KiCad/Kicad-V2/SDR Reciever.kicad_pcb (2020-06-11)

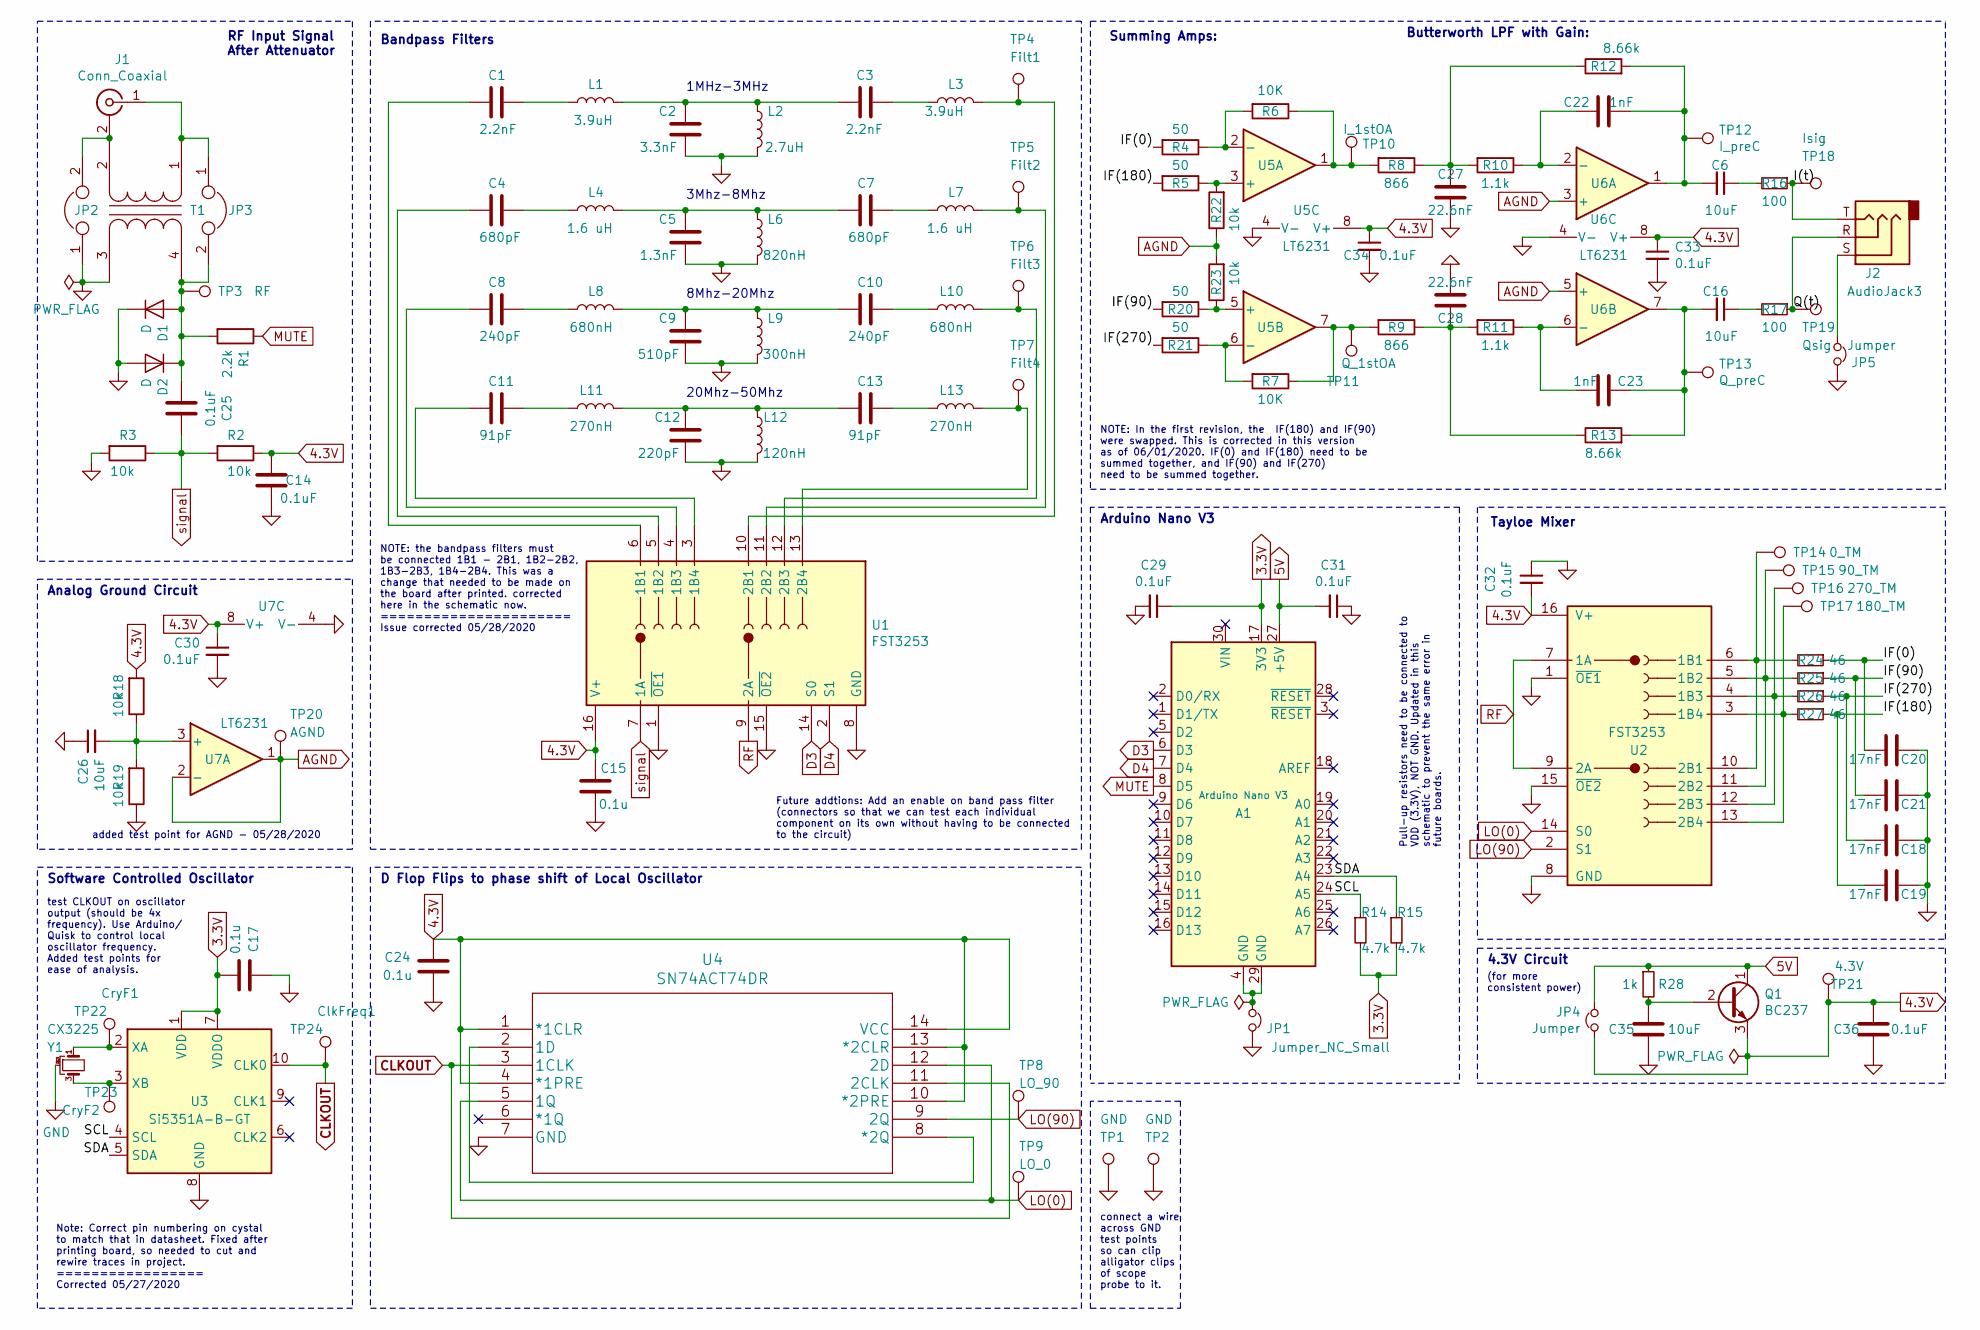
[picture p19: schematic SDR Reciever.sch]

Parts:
A1: Arduino Nano V3; Arduino_Nano
C1, C3: 2.2nF; C_0805_2012Metric
C2: 3.3nF; C_0805_2012Metric
C4, C7: 680pF; C_0805_2012Metric
C5: 1.3nF; C_0805_2012Metric
C6, C16, C26, C35: 10uF; C_0805_2012Metric
C8, C10: 240pF; C_0805_2012Metric
C9: 510pF; C_0805_2012Metric
C11, C13: 91pF; C_0805_2012Metric
C12: 220pF; C_0805_2012Metric
C14, C25, C29, C30, C31, C32, C33, C34, C36: 0.1uF; C_0805_2012Metric
C15, C17, C24: 0.1u; C_0805_2012Metric
C18, C19, C20, C21: 17nF; C_0805_2012Metric
C22, C23: 1nF; C_0805_2012Metric
C27, C28: 22.6nF; C_0805_2012Metric
ClkFreq1: TP24; TestPoint_Loop_D1.80mm_Drill1.0mm_Beaded
CryF1: TP22; TestPoint_Loop_D1.80mm_Drill1.0mm_Beaded
CryF2: TP23; TestPoint_Loop_D1.80mm_Drill1.0mm_Beaded
D1, D2: D; D_DO-35_SOD27_P7.62mm_Horizontal
J1: Conn_Coaxial; SMA_Molex_73251-1153_EdgeMount_Horizontal
J2: AudioJack3; Jack_3.5mm_Switronic_ST-005-G_horizontal
JP1: Jumper_NC_Small; PinHeader_1x02_P2.54mm_Vertical
JP2, JP3, JP4, JP5: Jumper; PinHeader_1x02_P2.54mm_Vertical
L1, L3: 3.9uH; L_Toroid_Vertical_L13.0mm_W6.5mm_P5.60mm
L2: 2.7uH; L_Toroid_Vertical_L13.0mm_W6.5mm_P5.60mm
L4, L7: 1.6 uH; L_Toroid_Vertical_L10.0mm_W5.0mm_P5.08mm
L6: 820nH; L_Toroid_Vertical_L10.0mm_W5.0mm_P5.08mm
L8: 680nH; L_Toroid_Vertical_L10.0mm_W5.0mm_P5.08mm
L9: 300nH; L_0805_2012Metric
L10: 680nH; L_0805_2012Metric
L11, L13: 270nH; L_0805_2012Metric
L12: 120nH; L_0805_2012Metric
Q1: BC237; TO-92_Inline
R1: 2.2k; R_0805_2012Metric
R2, R3, R18, R19, R22, R23: 10k; R_0805_2012Metric
R4, R5, R20, R21: 50; R_0805_2012Metric
R6, R7: 10K; R_0805_2012Metric
R8, R9: 866; R_0805_2012Metric
R10, R11: 1.1k; R_0805_2012Metric
R12, R13: 8.66k; R_0805_2012Metric
R14, R15: 4.7k; R_0805_2012Metric
R16, R17: 100; R_0805_2012Metric
R24, R25, R26, R27: 46; R_0805_2012Metric
R28: 1k; R_0805_2012Metric
T1: Transformer_1P_1S; Transformer_Toroid_Horizontal_D14.0mm_Amidon-T50
TP1, TP2: GND; TestPoint_Loop_D1.80mm_Drill1.0mm_Beaded
TP3: RF; TestPoint_Loop_D1.80mm_Drill1.0mm_Beaded
TP4: Filt1; TestPoint_Loop_D1.80mm_Drill1.0mm_Beaded
TP5: Filt2; TestPoint_Loop_D1.80mm_Drill1.0mm_Beaded
TP6: Filt3; TestPoint_Loop_D1.80mm_Drill1.0mm_Beaded
TP7: Filt4; TestPoint_Loop_D1.80mm_Drill1.0mm_Beaded
TP8: LO_90; TestPoint_Loop_D1.80mm_Drill1.0mm_Beaded
TP9: LO_0; TestPoint_Loop_D1.80mm_Drill1.0mm_Beaded
TP10: I_1stOA; TestPoint_Loop_D1.80mm_Drill1.0mm_Beaded
TP11: Q_1stOA; TestPoint_Loop_D1.80mm_Drill1.0mm_Beaded
TP12: I_preC; TestPoint_Loop_D1.80mm_Drill1.0mm_Beaded
TP13: Q_preC; TestPoint_Loop_D1.80mm_Drill1.0mm_Beaded
TP14: 0_TM; TestPoint_Loop_D1.80mm_Drill1.0mm_Beaded
TP15: 90_TM; TestPoint_Loop_D1.80mm_Drill1.0mm_Beaded
TP16: 270_TM; TestPoint_Loop_D1.80mm_Drill1.0mm_Beaded
TP17: 180_TM; TestPoint_Loop_D1.80mm_Drill1.0mm_Beaded
TP18: Isig; TestPoint_Loop_D1.80mm_Drill1.0mm_Beaded
TP19: Qsig; TestPoint_Loop_D1.80mm_Drill1.0mm_Beaded
TP20: AGND; TestPoint_Loop_D1.80mm_Drill1.0mm_Beaded
TP21: 4.3V; TestPoint_Loop_D1.80mm_Drill1.0mm_Beaded
U1, U2: FST3253; FST3253MX
U3: Si5351A-B-GT; MSOP-10_3x3mm_P0.5mm
U4: SN74ACT74DR
U5, U6, U7: LT6231; LT6231CS8-PBF
Y1: CX3225; Crystal_SMD_SeikoEpson_FA238-4Pin_3.2x2.5mm

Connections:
3.3V: A1.17 (3V3), C17.1, C29.1, R14.2, R15.2, U3.1 (VDD), U3.7 (VDDO)
4.3V: C14.2, C15.2, C24.2, C30.1, C32.2, C33.1, C34.1, C36.1, JP4.2, Q1.3 (E), R2.1, R18.2, TP21.1, U1.16 (V+), U2.16 (V+), U4.1 (*1CLR), U4.4 (*1PRE), U4.10 (*2PRE), U4.13 (*2CLR), U4.14 (VCC), U5.8 (V+), U6.8 (V+), U7.8 (V+)
5V: A1.27 (+5V), C31.2, JP4.1, Q1.1 (C), R28.1
/I(t): J2.T, R16.1, TP18.1
/IF(0): C20.1, R4.2, R24.1
/IF(90): C21.1, R20.2, R25.1
/IF(180): C19.1, R5.2, R27.1
/IF(270): C18.1, R21.2, R26.1
/Q(t): J2.R, R17.1, TP19.1
/SCL: A1.24 (A5), R14.1, U3.4 (SCL)
/SDA: A1.23 (A4), R15.1, U3.5 (SDA)
AGND: R22.1, R23.2, TP20.1, U6.3 (+), U6.5 (+), U7.1, U7.2 (-)
CLKOUT: ClkFreq1.1, U3.10 (CLK0), U4.3 (1CLK), U4.11 (2CLK)
D3: A1.6 (D3), U1.14 (S0)
D4: A1.7 (D4), U1.2 (S1)
GND: C2.1, C5.1, C9.1, C12.1, C14.1, C15.1, C17.2, C18.2, C19.2, C20.2, C21.2, C24.1, C26.1, C27.1, C28.2, C29.2, C30.2, C31.1, C32.1, C33.2, C34.2, C35.2, C36.2, D1.1 (K), D2.2 (A), JP1.1, JP2.1, JP5.1, L2.2, L6.2, L9.2, L12.2, R3.2, R19.1, T1.3 (SA), TP1.1, TP2.1, U1.1 (~OE1), U1.8 (GND), U1.15 (~OE2), U2.1 (~OE1), U2.8 (GND), U2.15 (~OE2), U3.8 (GND), U4.7 (GND), U5.4 (V-), U6.4 (V-), U7.4 (V-), Y1.2, Y1.4
LO(0): TP9.1, U2.14 (S0), U4.5 (1Q), U4.12 (2D)
LO(90): TP8.1, U2.2 (S1), U4.9 (2Q)
MUTE: A1.8 (D5), R1.1
unnamed: A1.4 (GND), A1.29 (GND), JP1.2
unnamed: C1.1, L1.1
unnamed: C1.2, U1.6 (1B1)
unnamed: C2.2, C3.1, L1.2, L2.1
unnamed: C3.2, L3.1
unnamed: C4.1, L4.1
unnamed: C4.2, U1.5 (1B2)
unnamed: C5.2, C7.2, L4.2, L6.1
unnamed: C6.1, R16.2
unnamed: C7.1, L7.1
unnamed: C8.1, L8.1
unnamed: C8.2, U1.4 (1B3)
unnamed: C10.1, L10.1
unnamed: C9.2, C10.2, L8.2, L9.1
unnamed: C11.1, L11.1
unnamed: C11.2, U1.3 (1B4)
unnamed: C12.2, C13.2, L11.2, L12.1
unnamed: C13.1, L13.1
unnamed: C16.1, R17.2
unnamed: C16.2, C23.1, R13.2, TP13.1, U6.7
unnamed: C6.2, C22.1, R12.2, TP12.1, U6.1
unnamed: C22.2, R10.1, U6.2 (-)
unnamed: C23.2, R11.1, U6.6 (-)
unnamed: C25.2, D1.2 (A), D2.1 (K), JP3.2, R1.2, T1.4 (SB), TP3.1
unnamed: C26.2, R18.1, R19.2, U7.3 (+)
unnamed: C27.2, R8.1, R10.2, R12.1
unnamed: C28.1, R9.1, R11.2, R13.1
unnamed: C35.1, Q1.2 (B), R28.2
unnamed: CryF1.1, U3.2 (XA), Y1.1
unnamed: CryF2.1, U3.3 (XB), Y1.3
unnamed: J1.1 (In), JP3.1, T1.1 (AA)
unnamed: J1.2 (Ext), JP2.2, T1.2 (AB)
unnamed: J2.S, JP5.2
unnamed: L3.2, TP4.1, U1.10 (2B1)
unnamed: L7.2, TP5.1, U1.11 (2B2)
unnamed: L10.2, TP6.1, U1.12 (2B3)
unnamed: L13.2, TP7.1, U1.13 (2B4)
unnamed: R4.1, R6.2, U5.2 (-)
unnamed: R6.1, R8.2, TP10.1, U5.1
unnamed: R7.1, R9.2, TP11.1, U5.7
unnamed: R20.1, R23.1, U5.5 (+)
unnamed: R7.2, R21.1, U5.6 (-)
unnamed: R5.1, R22.2, U5.3 (+)
unnamed: R24.2, TP14.1, U2.6 (1B1), U2.10 (2B1)
unnamed: R25.2, TP15.1, U2.5 (1B2), U2.11 (2B2)
unnamed: R26.2, TP16.1, U2.4 (1B3), U2.12 (2B3)
unnamed: R27.2, TP17.1, U2.3 (1B4), U2.13 (2B4)
unnamed: U4.2 (1D), U4.8 (*2Q)
RF: U1.9 (2A), U2.7 (1A), U2.9 (2A)
signal: C25.1, R2.2, R3.1, U1.7 (1A)

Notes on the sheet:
RF Input Signal After Attenuator
Bandpass Filters
3Mhz-8Mhz
20Mhz-50Mhz
Software Controlled Oscillator
Arduino Nano V3
Summing Amps:
Butterworth LPF with Gain:
Tayloe Mixer
1MHz-3MHz
8Mhz-20Mhz
connect a wire across GND test points so can clip alligator clips of scope probe to it.
test CLKOUT on oscillator output (should be 4x frequency). Use Arduino/ Quisk to control local oscillator frequency. Added test points for ease of analysis.
Note: Correct pin numbering on cystal to match that in datasheet. Fixed after printing board, so needed to cut and rewire traces in project. ================= Corrected 05/27/2020
Pull-up resistors need to be connected to VDD (3.3V), NOT GND. Updated in this schematic to prevent the same error in future boards.
NOTE: the bandpass filters must be connected 1B1 - 2B1, 1B2-2B2, 1B3-2B3, 1B4-2B4. This was a change that needed to be made on the board after printed. corrected here in the schematic now. ====================== Issue corrected 05/28/2020
added test point for AGND - 05/28/2020
Analog Ground Circuit
Future addtions: Add an enable on band pass filter (connectors so that we can test each individual component on its own without having to be connected to the circuit)
D Flop Flips to phase shift of Local Oscillator
4.3V Circuit
(for more consistent power)
NOTE: In the first revision, the IF(180) and IF(90) were swapped. This is corrected in this version as of 06/01/2020. IF(0) and IF(180) need to be summed together, and IF(90) and IF(270) need to be summed together.

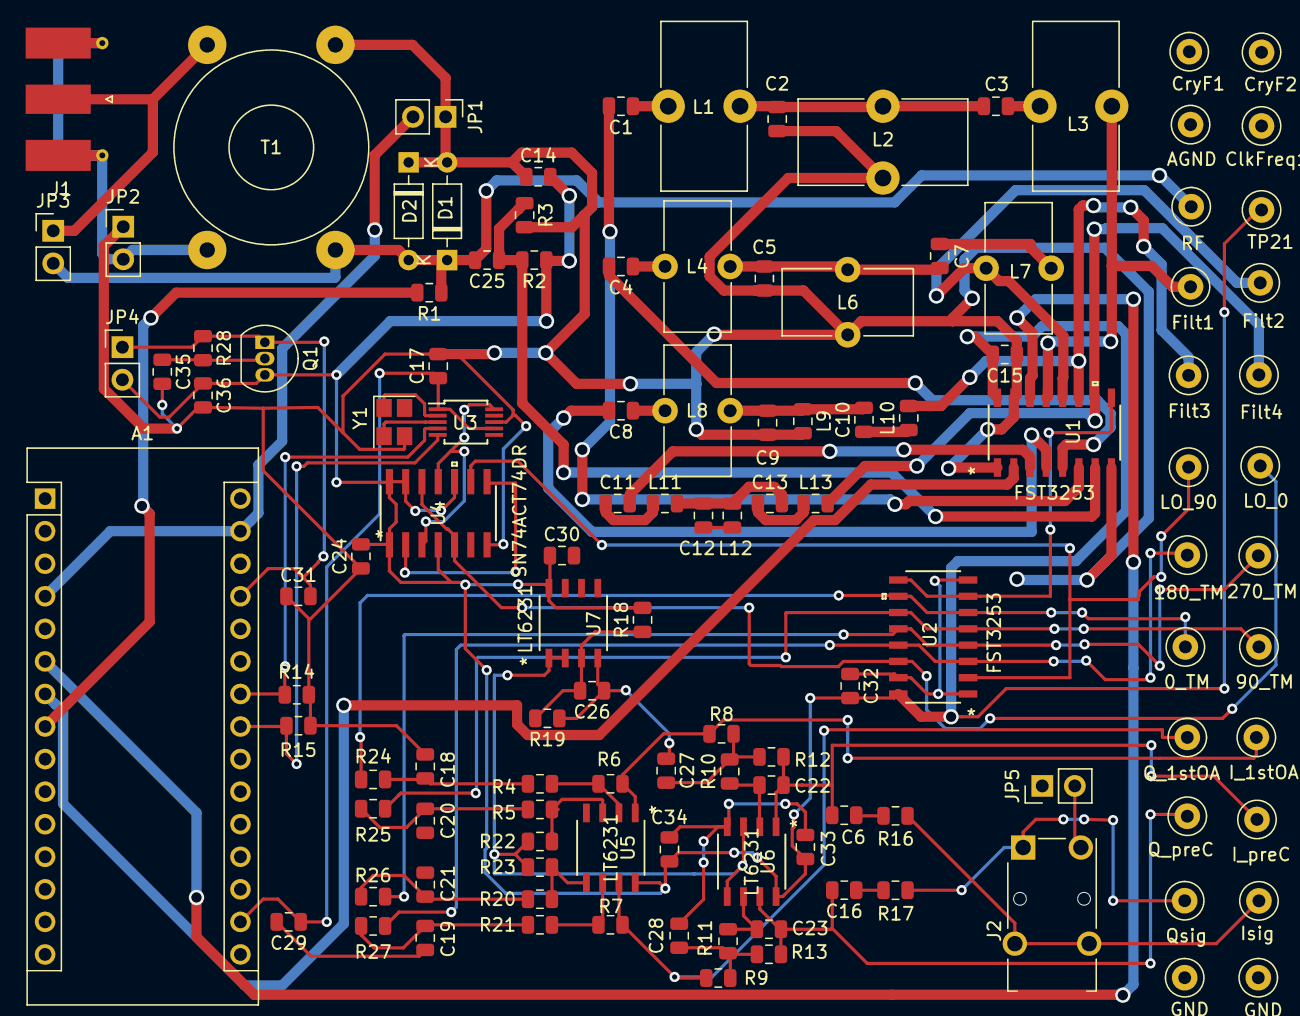
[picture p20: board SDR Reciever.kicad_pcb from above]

Board: 2 copper layers, 120 parts (0 on the bottom side), 69 nets.

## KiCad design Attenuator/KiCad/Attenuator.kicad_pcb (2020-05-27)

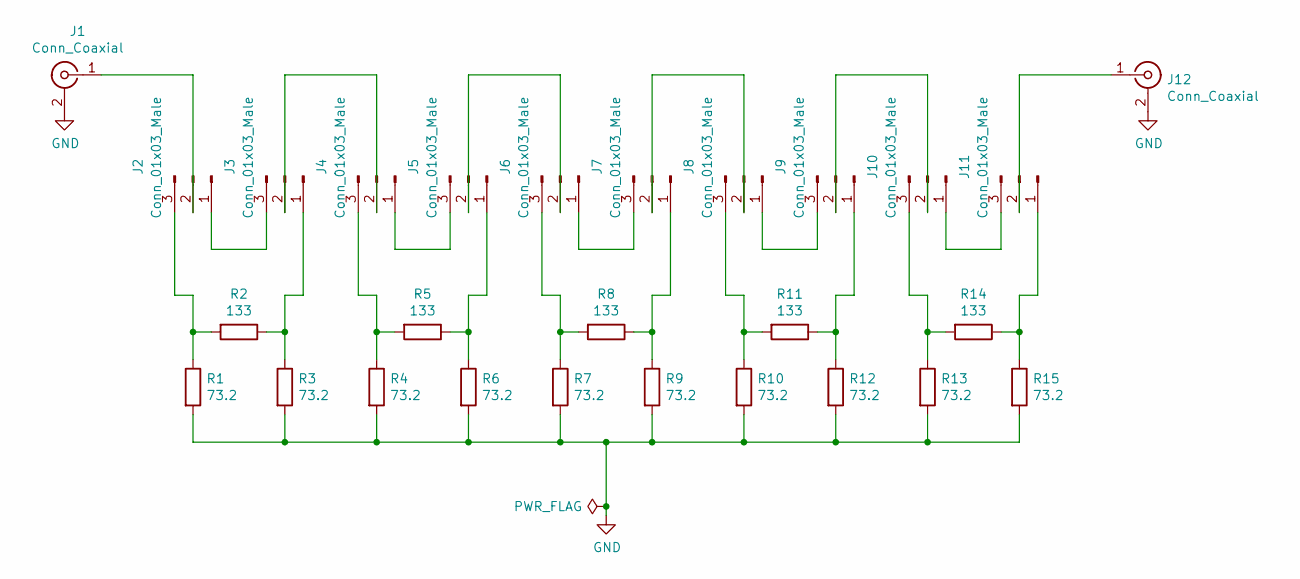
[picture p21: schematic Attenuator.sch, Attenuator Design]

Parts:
J1, J12: Conn_Coaxial; SMA_Molex_73251-1153_EdgeMount_Horizontal
J2, J3, J4, J5, J6, J7, J8, J9, J10, J11: Conn_01x03_Male; PinHeader_1x03_P2.54mm_Vertical
R1, R3, R4, R6, R7, R9, R10, R12, R13, R15: 73.2; R_Axial_DIN0207_L6.3mm_D2.5mm_P7.62mm_Horizontal
R2, R5, R8, R11, R14: 133; R_Axial_DIN0207_L6.3mm_D2.5mm_P7.62mm_Horizontal

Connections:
GND: J1.2 (Ext), J12.2 (Ext), R1.2, R3.2, R4.2, R6.2, R7.2, R9.2, R10.2, R12.2, R13.2, R15.2
unnamed: J1.1 (In), J2.2
unnamed: J2.1, J3.3
unnamed: J2.3, R1.1, R2.2
unnamed: J3.1, R2.1, R3.1
unnamed: J3.2, J4.2
unnamed: J4.1, J5.3
unnamed: J4.3, R4.1, R5.2
unnamed: J5.1, R5.1, R6.1
unnamed: J5.2, J6.2
unnamed: J6.1, J7.3
unnamed: J6.3, R7.1, R8.2
unnamed: J7.1, R8.1, R9.1
unnamed: J7.2, J8.2
unnamed: J8.1, J9.3
unnamed: J8.3, R10.1, R11.2
unnamed: J9.1, R11.1, R12.1
unnamed: J10.1, J11.3
unnamed: J9.2, J10.2
unnamed: J10.3, R13.1, R14.2
unnamed: J11.1, R14.1, R15.1
unnamed: J11.2, J12.1 (In)

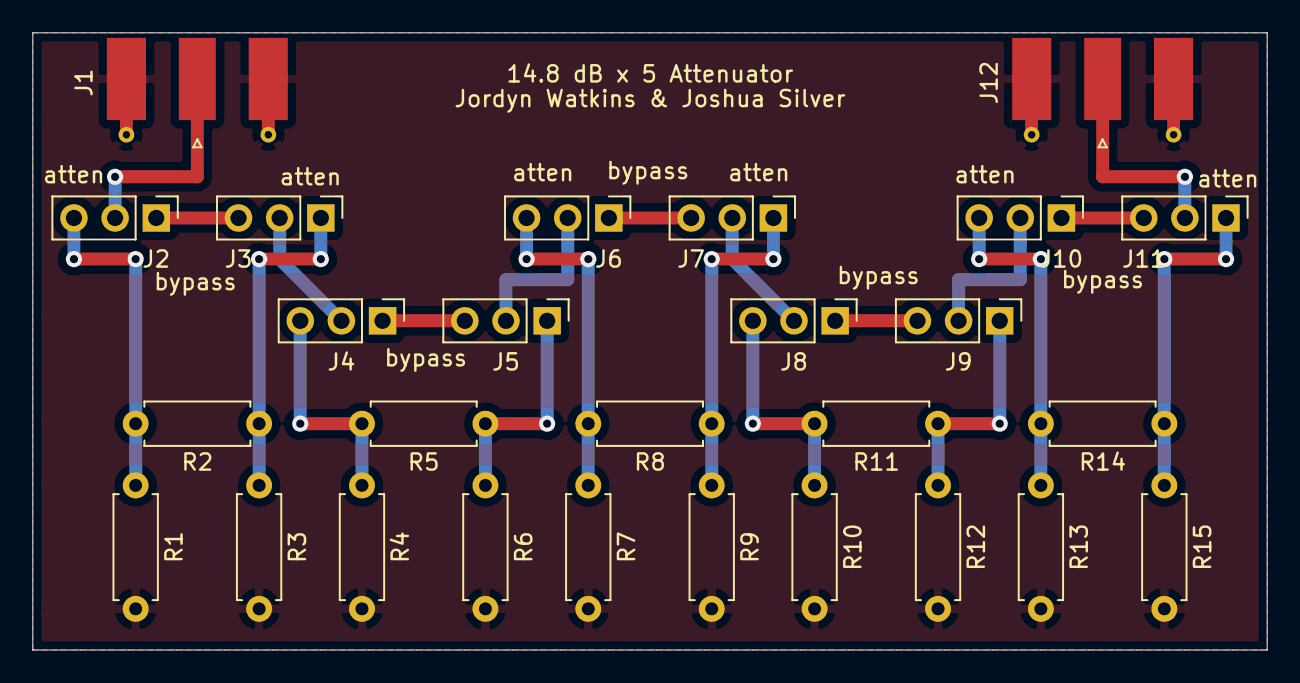
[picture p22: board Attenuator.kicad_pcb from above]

Board: 2 copper layers, 76.2 x 38.1 mm, 27 parts (0 on the bottom side), 22 nets.

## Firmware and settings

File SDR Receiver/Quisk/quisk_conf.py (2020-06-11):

# OpenRadio v1.1 Quisk Configuration File
# 
# IMPORTANT: To be able to control the OpenRadio board from within Quisk,
# you will need to compile and upload the 'openradio_quisk' firmware, which
# is available from: https://github.com/darksidelemm/open_radio_miniconf_2015
#
# You will also need to install the pyserial package for python.
#

from __future__ import print_function
from __future__ import absolute_import
from __future__ import division
from os import path
import sys
import wx

# SOUND CARD SETTINGS
#
sample_rate = 48000					# name_of_sound_capt hardware sample rate in Hertz
if sys.platform == "win32":
  name_of_sound_capt = "Primary"
  name_of_sound_play = "Primary"
elif sys.platform == "darwin":
  name_of_sound_capt = "pulse"
  name_of_sound_play = "pulse"
else:
  name_of_sound_capt = "pulse"		# Name of soundcard capture hardware device.
  name_of_sound_play = "pulse"
channel_i = 1 					# Soundcard index of in-phase channel:  0, 1, 2, ...
channel_q = 0						# Soundcard index of quadrature channel:  0, 1, 2, ...

# SERIAL PORT SETTINGS
# Set this as appropriate for your OS.
if path.exists("/dev/cu.wchusbserial1410"):
  openradio_serial_port = "/dev/cu.wchusbserial1410"
elif path.exists("/dev/cu.wchusbserial1410"):
  openradio_serial_port = "/dev/cu.wchusbserial1410"
openradio_serial_rate = 57600


# OpenRadio Frequency limits.
# These are just within the limits set in the openradio_quisk firmware.
openradio_lower = 100001
openradio_upper = 29999999

# OpenRadio Hardware Control Class
#
import serial,time
from quisk_hardware_model import Hardware as BaseHardware

class Hardware(BaseHardware):
  def open(self):
    # Called once to open the Hardware
    # Open the serial port.
    self.or_serial = serial.Serial(openradio_serial_port,openradio_serial_rate,timeout=3)
    print("Opened Serial Port.")
    # Wait for the Arduino Nano to restart and boot.
    time.sleep(2)
    # Poll for version. Should probably confirm the response on this.
    version = str(self.get_parameter("VER"))
    print("This should be the version printed next.")
    print(version)
    # Return an informative message for the config screen
    t = version + ". Capture from sound card %s." % self.conf.name_of_sound_capt
    return t

  def close(self):      
    # Called once to close the Hardware
    self.or_serial.close()

  def ChangeFrequency(self, tune, vfo, source='', band='', event=None):
    # Called whenever quisk requests a frequency change.
    # This sends the FREQ command to set the centre frequency of the OpenRadio,
    # and will also move the 'tune' frequency (the section within the RX passband
    # which is to be demodulated) if it falls outside the passband (+/- sample_rate/2).
    print("Setting VFO to %d." % vfo)
    if(vfo<openradio_lower):
      vfo = openradio_lower
      print("Outside range! Setting to %d" % openradio_lower)

    if(vfo>openradio_upper):
      vfo = openradio_upper
      print("Outside range! Setting to %d" % openradio_upper)

    success = self.set_parameter("FREQ",str(vfo))

    print("sample_rate =")
    print(sample_rate)
    # If the tune frequency is outside the RX bandwidth, set it to somewhere within that bandwidth.
    if(tune>(vfo + sample_rate/2) or tune<(vfo - sample_rate/2)):
      vfo = tune -10000  #We don't care so much about the VFO.
      print("Bringing tune frequency back into the RX bandwidth.")

    if success:
      print("Frequency change succeeded!")
    else:
      print("Frequency change failed.")

    return tune, vfo

#
# Serial comms functions, to communicate with the OpenRadio board
#

  def get_parameter(self,string):
    string = string + "\n"
    self.or_serial.write(string.encode())
    return self.get_argument()
    #return string.encode()
        
  def set_parameter(self,string,arg):
    string = string+","+arg+"\n"
    self.or_serial.write(string.encode())
    if self.get_argument() == arg:
      return True
    else:
      return False
    
  def get_argument(self):
    data1 = self.or_serial.readline()
    # Do a couple of quick checks to see if there is useful data here
    if len(data1) == 0:
       return -1
        
    # Maybe we didn't catch an OK line?
    if data1.startswith(b'OK'):
       data1 = self.or_serial.readline()
        
    # Check to see if we have a comma in the string. If not, there is no argument.
    if data1.find(b',') == -1:
       return -1
    
    data1 = data1.split(b',')[1].rstrip(b'\r\n')
    print("data1 =")
    print(data1)
    
    # Check for the OK string
    data2 = self.or_serial.readline()
    if data2.startswith(b'OK'):
       return data1

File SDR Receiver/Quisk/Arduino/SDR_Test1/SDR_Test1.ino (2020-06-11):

#include "si5351.h"
#include "Wire.h"

Si5351 si5351;

void setup()
{
  bool i2c_found;
  i2c_found = si5351.init(SI5351_CRYSTAL_LOAD_8PF, 0, 0);
  si5351.set_freq(4*75000000ULL, SI5351_CLK0);
  Serial.begin(115200);
  pinMode(6, OUTPUT);
  pinMode(7, OUTPUT); 
  digitalWrite(6, LOW); // D3 (s0)
  digitalWrite(7, LOW);  // D4 (s1)
}



void loop()
{
  si5351.update_status();
  Serial.print("SYS_INIT: ");
  Serial.print(si5351.dev_status.SYS_INIT);
  Serial.print("  LOL_A: ");
  Serial.print(si5351.dev_status.LOL_A);
  Serial.print("  LOL_B: ");
  Serial.print(si5351.dev_status.LOL_B);
  Serial.print("  LOS: ");
  Serial.print(si5351.dev_status.LOS);
  Serial.print("  REVID: ");
  Serial.println(si5351.dev_status.REVID);
}

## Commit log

2020-05-27 Add files via upload
    Added Frohro 's Arduino test file
2020-05-27 Add files via upload
    Attenuator Files Uploaded -- files need to be revised to match corrections that need to be made in the project
    [Attenuator-B_Cu.gbr, Attenuator-B_Mask.gbr, Attenuator-B_Paste.gbr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]
2020-05-27 Add files via upload
    Receiver files uploaded --- files need to be revised and cleaned up to match corrections that need to be made on the project
    [SDR Reciever-B_Cu.gbl, SDR Reciever-B_Mask.gbs, SDR Reciever-B_Paste.gbp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]
2020-05-27 Add files via upload
    Quisk files and Arduino Code from Frohro github
2020-06-11 added pdf document of updated schematic

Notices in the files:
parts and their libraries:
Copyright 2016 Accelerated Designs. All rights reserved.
